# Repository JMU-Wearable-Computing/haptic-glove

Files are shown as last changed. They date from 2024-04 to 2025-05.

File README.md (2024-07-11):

# haptic-glove

## Haptic Effect Waveforms
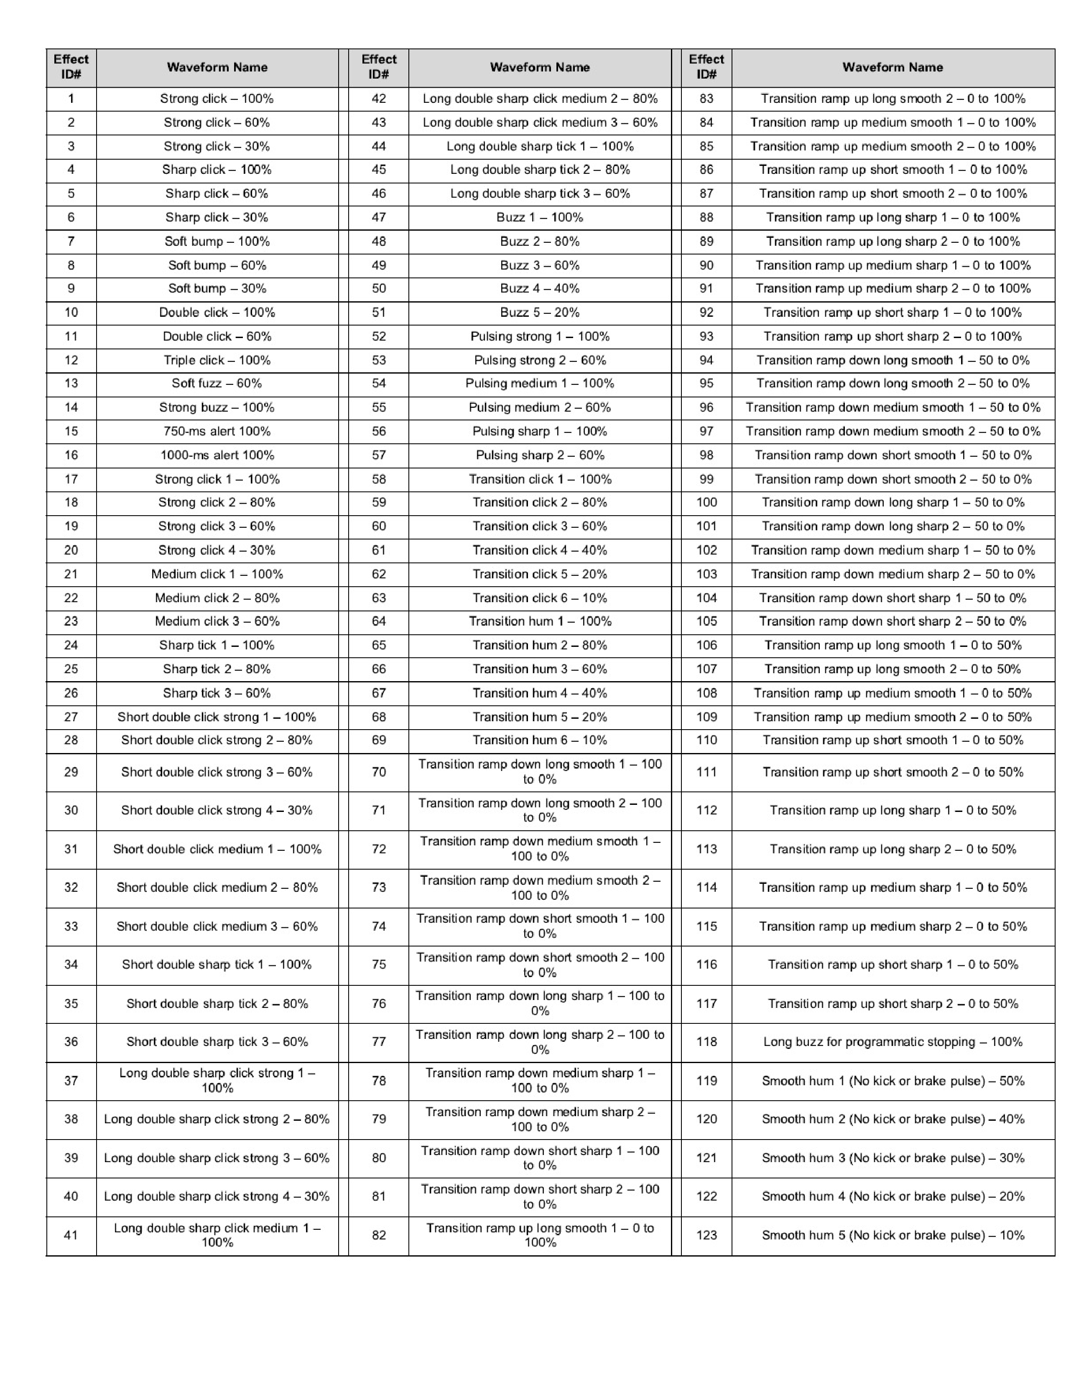
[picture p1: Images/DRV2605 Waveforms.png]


[Image source](https://learn.adafruit.com/assets/72593)

## PCB (Printed Circuit Board)

### Schematic V2.1
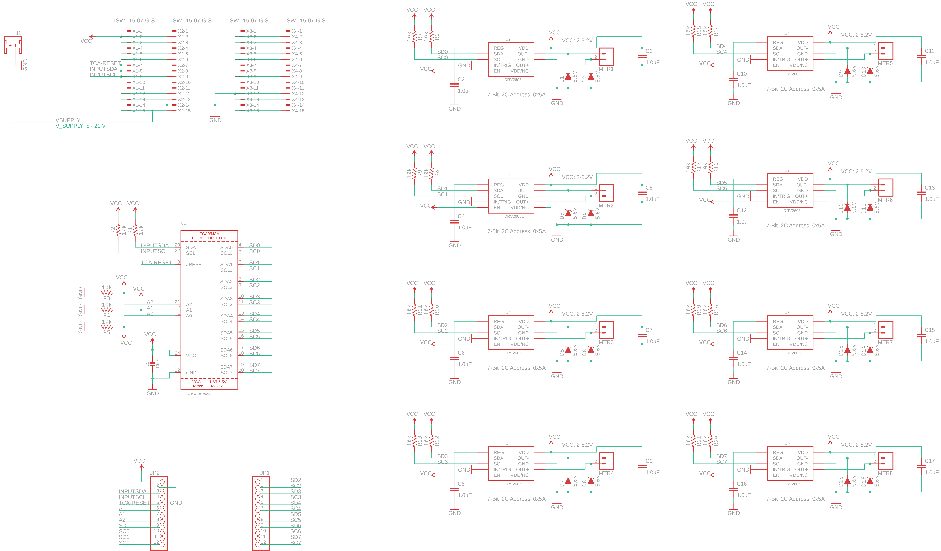
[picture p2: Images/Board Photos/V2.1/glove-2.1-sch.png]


### Layout V2.1
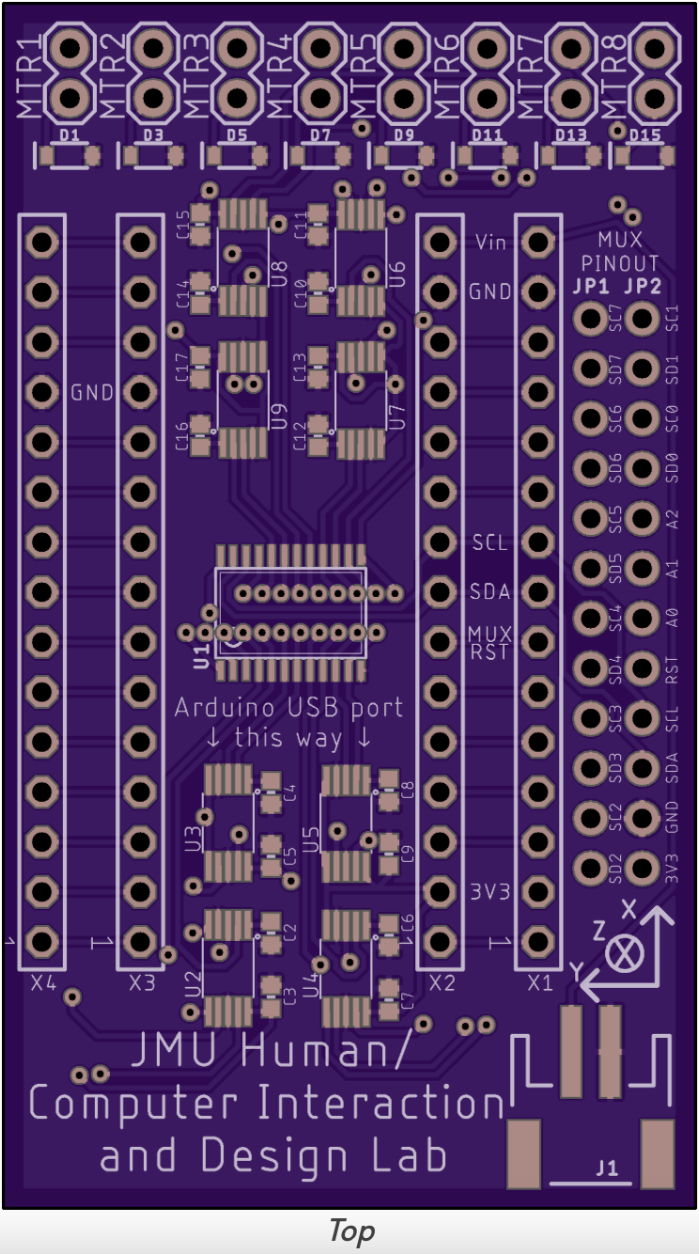
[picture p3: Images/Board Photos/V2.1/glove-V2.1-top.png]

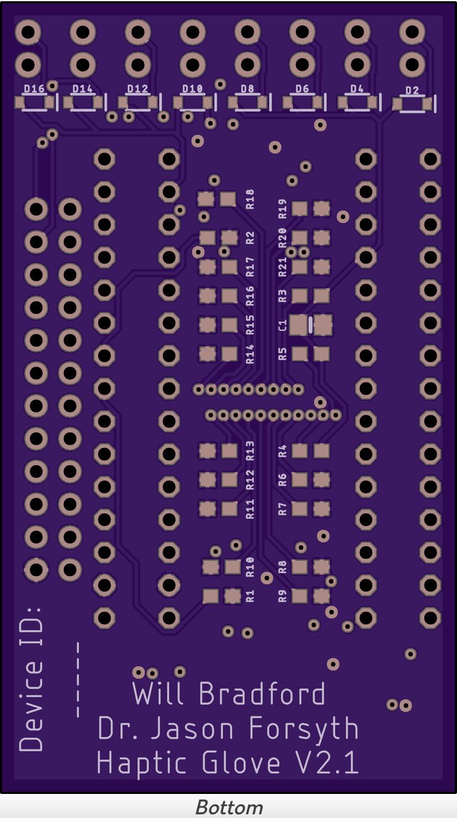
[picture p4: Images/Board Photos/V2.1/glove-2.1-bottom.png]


#### PCB Edit History
##### V2.0
- Initial board redesign
##### V2.1
- Shifted Arduino placement down 1 mm to allow for more clearance between the Arduino and the motor header pins
- Added graphic to denote onboard IMU directions
- Added a spot on the back of the board to write the board's device ID
- Shifted some silkscreen placements so that part names are not cut off by pads
- Added text to denote correct Arduino orientation
  
## Eagle PCB Set-Up

### OSHPark Plugin
The OSHPark Eagle plugin includes OSHPark design rules and allows the user to send the .brd file directly to an OSHPark cart. See the [OSHPark-Eagle-Tools GitHub](https://github.com/OSHPark/OSHPark-Eagle-Tools)

### Libraries
Included in the repository are:
1. TCA9548APWR.lbr (I2C multiplexer)
2. SparkFun-Eagle-Libraries-main.zip

## Arduino Nano Arduino IDE setup 

### Correct IDE version
Arduino IDE 2.X.X

### Correct board library and name:
#### Board Library
Arduino SAMD Boards (32-bits ARM Cortex-M0+)

#### Board Name
Arduino NANO 33 IoT

### Arduino Libraries
 
1. Adafruit_DRV2605.h
2. Arduino_LSM6DS3.h
3. WiFiNINA.h

### Troubleshooting
Sometimes, Arduino IDE fails to recognize that Nano 33 IoT is connected to a USB port. Should this happen, try the following fixes:
- Attempt to connect it to other USB ports on your machine
- If the above does not work, quickly double click the `RST` button on the Arduino while it is plugged into your machine. This will cause your Arduino's bootloader to run indefinitely. You will know that it has entered this state when you see the onboard LED slowly pulsing on and off. Arduino IDE should now recognize it and you should now be able to upload code.

If neither of these options work, then it is likely that either

(A). the bootloader on the Arduino is missing or corrupted, or  
(B). there is some hardware damage on the Arduino.

Sources: [Forum post 1](https://forum.arduino.cc/t/solved-arduino-nano-33-iot-not-recognized-by-windows-10/621376) & [Forum post 2](https://forum.arduino.cc/t/arduino-nano-33-iot-not-recognized-by-pc/1192703/4)

## Communicating with Nano 33 IoT

Nano 33 IoT can be communicated with via TCP socket connection.
Network credentials can be modified with the `ssid` and `password` variables within the Arduino code.
When booted, the Nano 33 IoT establishes a user definable static IP.

### Onboard LED state meanings
|State|Meaning|
--- | --- |
|OFF|Not connected to network|
|ON|Connected to user specified network|

### Message format
Messages follows the format: `X,n01,n02,n03,n04,n05,n06,n07,n08`

**NOTE FOR SERIAL COMMUNICATION ONLY:** Despite the known issue with [the dastardly eighth motor driver](#the-dastardly-eighth-motor-driver), the message format remains the same. Even if you are not using all eight drivers in your application with Serial communication, values for all eight drivers should be passed if you are sending an [effect message](#effect-messages) unless you are sending an [all stop message](#all-stop-message).

X is a char that signifies the message type. nXX is a number.
Negative numbers will be ignored and the playback of the current haptic effect will continue.
0 will stop the corresponding driver.
All decimals will be rounded DOWN.
Each segment of the message correspondes to the strength of a specific haptic driver, where n01 controls driver 1, n02 controls driver 2, and so on.

#### Effect Messages
For messages of type 'E', numbers [1, 123] will set the playback effect of the corresponding driver.
Numbers higher than 123 will set the playback effect to effect # 123.

##### All Stop Message
Should you want to halt the haptic playback of all drivers, simply passing `'E'` as the entire effect message will do this.

##### Example
The message `'E',100,43,55,1,123,34,99,2` will cause driver one to activate using haptic effect # 100, driver two to activate using haptic effect # 43, and so on. Passing the message `'E',0,-1,100.7,9999,0,0,0,0` afterwards will stop drivers 1, 5, 6, 7, and 8. Driver 2 will remain activated with the same haptic effect as before (# 43), driver 3 will activate using haptic effect # 100, and driver 4 will activate using haptic effect # 123.

#### Acceleration Messages
For messages of type 'A', numbers are used to toggle the continuous collection of acceleration data. Only one number should be passed. Passing the number zero will halt data collection, while any other number will resume data collection. For simplicity's sake, it is recommended to only use the number one to resume data collection. Once started, data will be continuously returned and sent to the client until another acceleration message is recieved that instructs the system to halt data collection.

##### Example
The message `'A',1` will begin continuous acceleration data collection and sending. The message `'A',0` will halt all acceleration data collection and sending.

## Tutorials
### Arduino IDE setup
This will teach you how to set up the Arduino IDE for use of the haptic glove. Prior to following this tutorial, you should already have the Arduino IDE downloaded.

1. Open `firmware-V2.ino`. `network_cred.h` should automatically open in a separate tab
2. Click the `network_cred.h` tab at the top and input your WiFi credentials. Press <kbd>Command</kbd> + <kbd>S</kbd> to save your edits on a Mac (<kbd>Control</kbd> + <kbd>S</kbd> on Windows).
3. Open the Boards Manager by clicking the correct icon on the left of the IDE. Search for `nano 33 iot`. The one board library that should be shown is `Arduino SAMD Boards (32-bits ARM Cortex-M0+)`. Install this library. Feel free to install a newer version than what is shown in the picture.

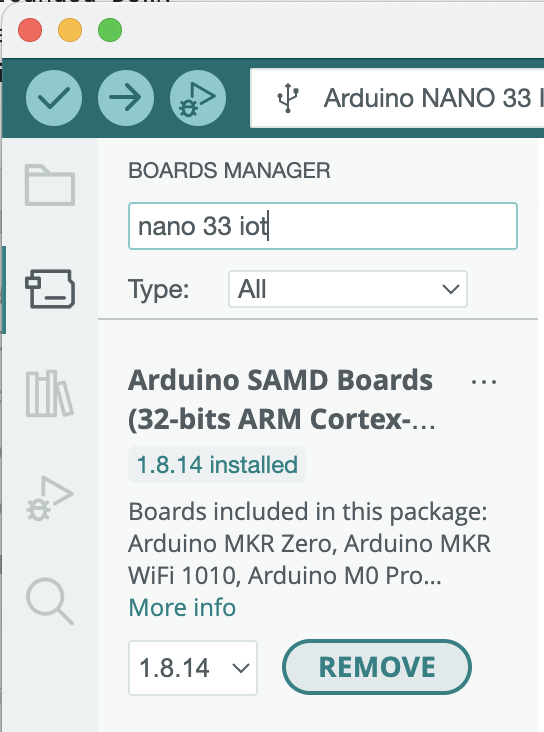
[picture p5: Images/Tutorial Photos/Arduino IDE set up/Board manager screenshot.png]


4. Open the Library manager by clicking the correct icon on the left of the IDE. Search for and install `Adafruit DRV2605 Library`, `Arduino_LSM6DS3` and `WiFiNINA`. Feel free to install newer versions than what are shown in the pictures.

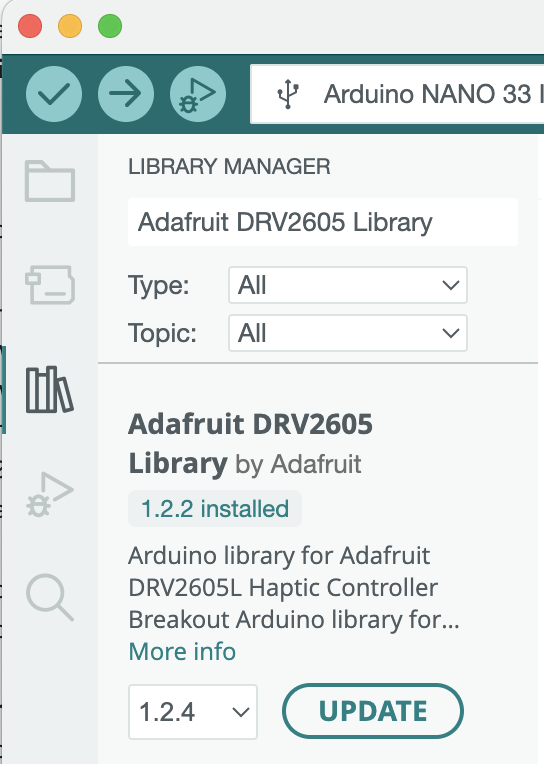
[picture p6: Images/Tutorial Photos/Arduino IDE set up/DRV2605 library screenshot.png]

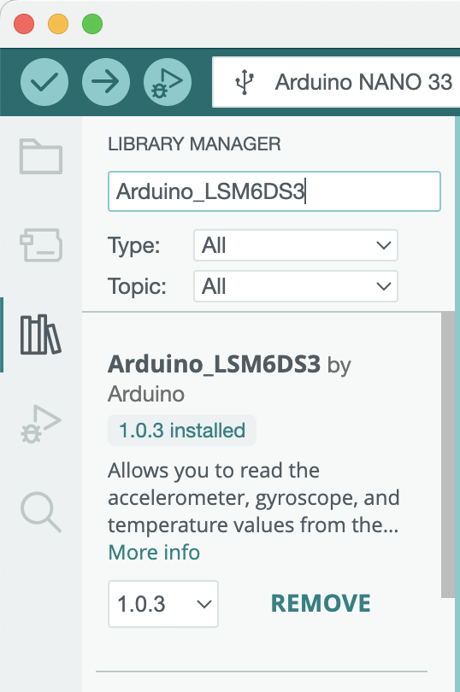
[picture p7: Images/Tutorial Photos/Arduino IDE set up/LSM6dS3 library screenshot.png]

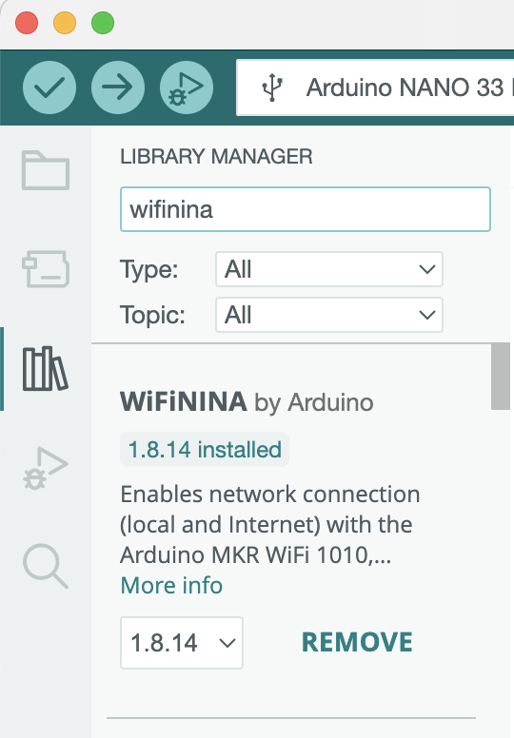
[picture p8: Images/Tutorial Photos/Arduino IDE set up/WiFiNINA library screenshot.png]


5. Navigate to `Tools`>`Board`>`Arduino`>`SAMD Boards (32-bits ARM Cortex-M0+)` and select `Arduino Nano 33 IoT` as the board.
6. Congratulations! Arduino IDE is now set up to be used with the haptic glove.

### Communicating with the Arduino via serial port
This will teach you how to send messages to the Arduino via the Serial port that will control the haptic motor drivers and the onboard IMU.

#### Initial Arduino set up
1. Complete the [Arduino IDE setup tutorial](#arduino-ide-setup).
2. Set the user-definable variables in the firmware. The value of the variable `DEVICE_ID` does not matter when using serial communication.



**NOTE:** See the [Known Issues section](#known-issues) for an explanation of `theDastardlyEighthDriver`

3. Ensure that the Serial Monitor baud rate is set to 9600



4. Connect the Arduino to your computer via USB, ensure the correct board and port are selected in the Arduino IDE, and upload the firmware by clicking the arrow button in the top left of the IDE.

#### Example Use
We will use an example message that was used in the [Message Format section](#message-format). Feel free to use other example messages from that section to familiarize yourself with the message structure. Or, be brave and create your own message (just be sure to follow the correct structure!)

##### Turning all drivers on with an effect message
1. In the serial monitor, type the following message and then press <kbd>Enter</kbd> (enter it EXACTLY as it appears here): `E,100,43,55,1,123,34,99,2`



2. If the variable `debug` is set to `true`, the following should be the last of what prints to the Serial Monitor:

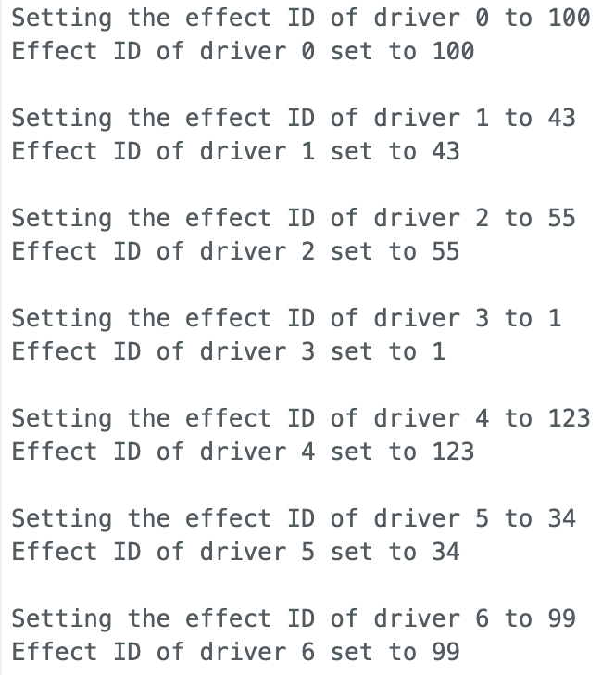
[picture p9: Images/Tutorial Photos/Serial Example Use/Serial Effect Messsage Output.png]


3. All drivers should now be activated. Driver number 1 should be set to haptic effect # 100, driver number 2 should be set to haptic effect # 43, and so on.

##### Accessing the accelerometer data using an acceleration message
1. In the serial monitor, type the following message and then press <kbd>Enter</kbd> (enter it EXACTLY as it appears here): `A,1`



2. As long as the variable `debug` is set to `true`, the following should print to the Serial Monitor. `outMsg` is the object that is sent to the TCP client. Acceleration data is now being continuously collected.

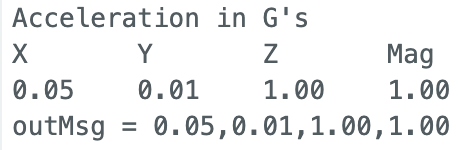
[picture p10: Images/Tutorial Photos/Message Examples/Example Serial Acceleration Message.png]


3. Now input the message `A,0` or just simply `A` into the Serial Monitor. Notice how the continuous collection of accelerometer data has stopped.

### Communicating with the Arduino via TCP socket connection
This will teach you how to send messages to the Arduino via a TCP socket to control the haptic motor drivers and the onboard IMU.

#### Initial Arduino set up
1. Complete the [Arduino IDE setup tutorial](#arduino-ide-setup).
2. Set the user-definable variables in the firmware. Be sure to set `DEVICE_ID` to a unique integer [10, 100].



3. Connect the Arduino to your computer via USB, ensure the correct board and port are selected in the Arduino IDE, and upload the firmware by clicking the arrow button in the top left of the IDE.
4. Once uploaded, you can safely unplug the Arduino from your computer. Congratulations! Your Arduino now has the necessary software and is ready for use with the haptic glove.

#### Setting up Python
This assumes that you already have Python installed and can successfully run a Python script.
1. Clone this repository (glove-V2) to your local computer
2. Open the repository in your preferred IDE (PyCharm is recommended)
3. Congrats! Python is now ready for use with the haptic glove.

#### Example Use
We will use `glove-demo-single.py` for this example. This is meant as a demonstration of the glove-V2 capabilities so that you can go on and create your own applications using the same methods.

1. After cloning this repository, open `glove-demo-single.py`
2. Ensure the correct parameters are set for the Glove object (`device_id`, `port`, `acceleration`, and `verbose`). Explanations for these parameters are in this Python file
3. The demo script is now ready for use. You can go ahead and run it, or customize the effect numbers that are sent to the glove.

**NOTE:** If you choose to activate the accelerometer on the Arduino (this is the default) then be sure that the `acceleration` property of the glove object is set to `True`. This will turn on continuous transmission of acceleration data until the Python script ends. Be sure that `glove.accel_loop` is set to `False` at the end of this example script. Otherwise, the program will be stuck in a loop and will continue to output acceleration data until the program is manually killed.

## Known Issues
### The Dastardly Eighth Motor Driver
#### Explanation and Recommendation
If you are attempting to control the motor drivers via TCP socket connection, attempting to activate the eighth driver (including if you tell it to halt effect playback by passing a zero in the correct place in an [effect message](#effect-messages) when it is already not activated) will cause the WiFi to disconnect. This will prevent reconnection until the onboard WiFi chip is fully turned off/on again by calling `WiFi.end()` and then the custom `WiFiConnect()` function that performs all of the initial WiFi connection procedures. Because of the nature of TCP socket connections, this requires the Arduino and desktop computer to restart their connection and create a new socket and client, at which point the problem will (99 times out of 100) happen again. To remedy this, the boolean variable `theDastardlyEighthDriver` has been added to the firmware that controls the use of the eighth driver. If you are at all using TCP socket connections with the haptic glove, be sure to keep this variable set to `false` so that the WiFi disconnect problem does not occur. You will only be able to use seven of the eight drivers, but the WiFi connection will be reliable and shouldn't drop. If you are strictly using Serial communication to control the motor drivers, then feel free to set `theDastardlyEighthDriver` to `true`. This will allow you to use all eight drivers for your application.
#### Potential Cause
The current theory for why this issue is happening is that the moment the I2C multiplexer begins to communicate with this eighth driver, since the driver's I2C lines are tied high and the mux pulls them low to communicate, power and ground are very briefly shorted. It is believed that this short then messes with the WiFi chip's power supply, causing WiFi to drop and requiring the WiFi chip to be reset.

This issue is present on all of the existing haptic glove V2.0 boards, so it is not believed that it is simply an issue with the soldering of the components, however this is still a possibility. However, it may be a tolerance issue with the traces on the PCB itself. As of now (May 2024), no V2.1 boards have been fabricated so it is unknown if this issue is present on those (although it is likely that it is). Also, it is worth noting that during fabrication of the PCBs there was a power-ground short somewhere that disappeared before we could track down the cause. It disappeared once all components were soldered onto the PCB. This may be related to the problem explained above, although there is no corroborating evidence to prove that this is the case.

The true cause of this issue is unknown, so it is best to utilize the `theDastardlyEighthDriver` variable to only use seven drivers if your application uses TCP sockets.

# Recommendations for Future Work
## Software Development
### General
Explore both `firmware-V2` and the Python scripts to both:
- Familiarize yourself with the workings of each, and
- Look at and address the various "TODO:" comments that are shrewn throughout.
### VS Code
Install [PlatformIO](https://docs.platformio.org/en/latest/integration/ide/vscode.html#ide-vscode) for VS Code to develop Arduino code. Also look at [this link](https://docs.platformio.org/en/latest/boards/atmelsam/nano_33_iot.html#board-atmelsam-nano-33-iot) to learn how to set up VS Code to use the Nano 33 IoT within PlatformIO.
### Checksum/Parity Check
Implement a checksum to verify the authenticity of each message recieved over TCP Socket
- We ran into some trouble implementing this, so we abandoned our efforts since this is a secondary feature that is not necesary for the design. There is already some rudimentary draft code in `firmware-V2` and `glove.py`
### Implementing Threads
Update `firmware-V2` to utilize threads for each main process (managing WiFi & onboard LED, controlling the haptic motor drivers, and receiving/parsing messages from both Serial and TCP Socket). We have been looking at and prototyping with [Arduino Free RTOS SAMD21](https://github.com/BriscoeTech/Arduino-FreeRTOS-SAMD21/tree/master) for this.
#### Onboard LED state meanings
Make it to where the below table is what happens
|State|Meaning|
--- | --- |
|OFF|Not connected to network|
|BLINKING|Connected to user specified network|
|SOLID|TCP client connected and ready for messages|

### Message Parser
#### Implement custom parser rather than strtok()
Currently, `firmware-V2` uses the built in function `strtok()` to parse received messages. This function has state and remembers the delimeter. Change the parsing process to use a custom parser so that this pipeline is more reliable and does not have state.
#### Make message system more robust
- Sometimes the software freezes if message does not contain instructions for all 8 motors

## Debugging the Arduino using an Atmel-ICE
Look into some surface mounted pins or magnetic pins to access the Arduino's debug pins on the underside of the Arduino. Learn how to use the Atmel-ICE to interface with these pins to debug the Arduino. Refer to [this PlatformIO link](https://docs.platformio.org/en/latest/boards/atmelsam/nano_33_iot.html#board-atmelsam-nano-33-iot) and [this SAM-based Arduino debugging tutorial](https://docs.arduino.cc/tutorials/mkr-wifi-1010/atmel-ice/) for reference for the beginning of your search of how to debug the Nano 33 IoT with the Atmel-ICE.

## Reworking Python Haptic Glove Game & Demo to Work with Glove V2
The lab's glove demos currently only work with V1 of both the glove and Python code. Update these demos to work with the V2 glove and Python code. This will likely require some internal restructuring of the demos themselves.

## PCB Revision
### 5V Step Up Converter
When using battery power for glove V2, a 5V boost/step up converter must be used to provide the Arduino with enough voltage. as of Spring 2024, we are using a [PowerBoost 1000 Basic](https://www.adafruit.com/product/2030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) breakout board from Arduino for this. Make a new PCB revision that includes this boost converter and all required circuitry onto the PCB itself.

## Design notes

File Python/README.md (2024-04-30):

glove.py = Base class for haptic glove object

glove-demo-single.py = Example to test haptic motor functionality of one glove

glove-demo-multiple.py = Example to test haptic motor functionality of two or more gloves

echo.py = Echo script to test TCP socket communication

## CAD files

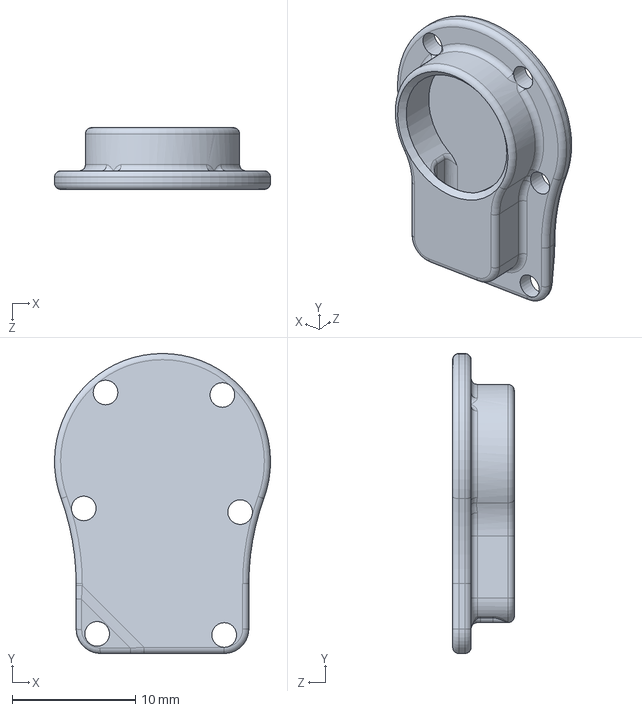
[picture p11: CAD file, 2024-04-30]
Solidworks/Haptic motor housing.SLDPRT
17.5 x 24.3 x 5.00 mm

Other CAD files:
Solidworks/Haptic motor housing.STL

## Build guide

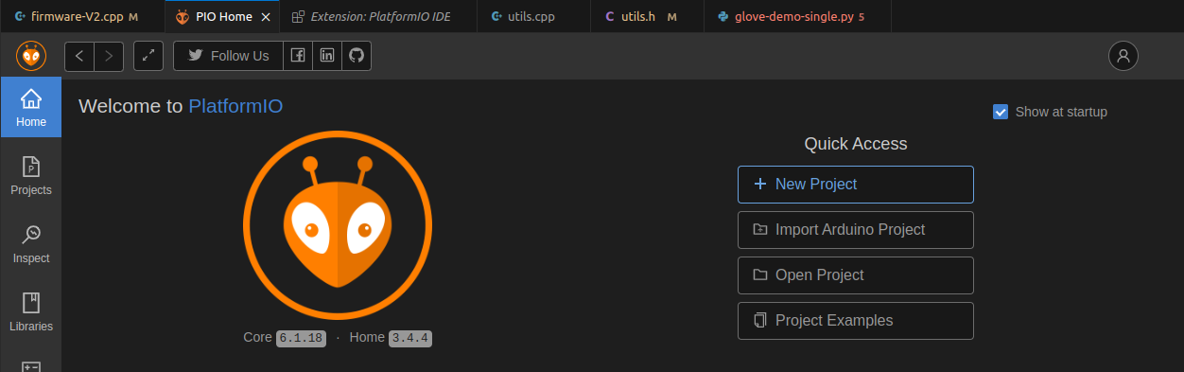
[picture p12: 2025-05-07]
Images/Tutorial Photos/PlatformIO Setup/add_new_project.png

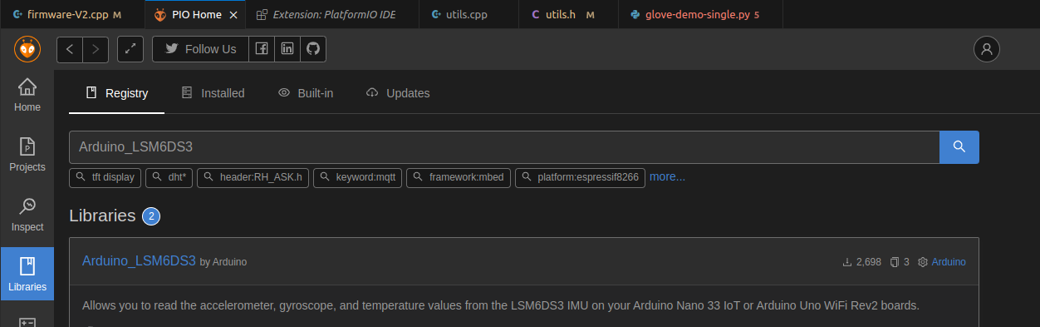
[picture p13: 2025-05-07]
Images/Tutorial Photos/PlatformIO Setup/lsm_library.png

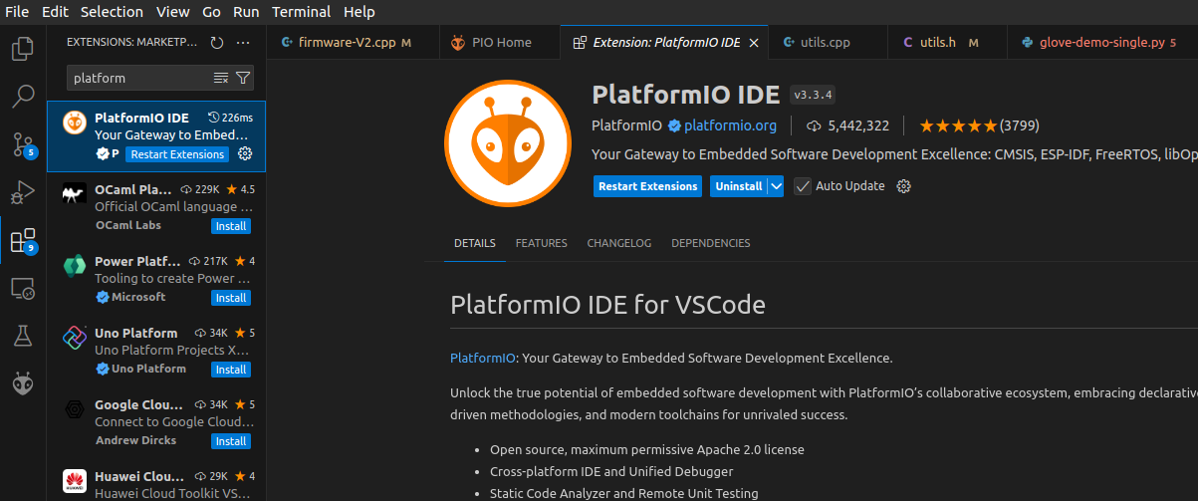
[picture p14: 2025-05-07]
Images/Tutorial Photos/PlatformIO Setup/install_extension.png

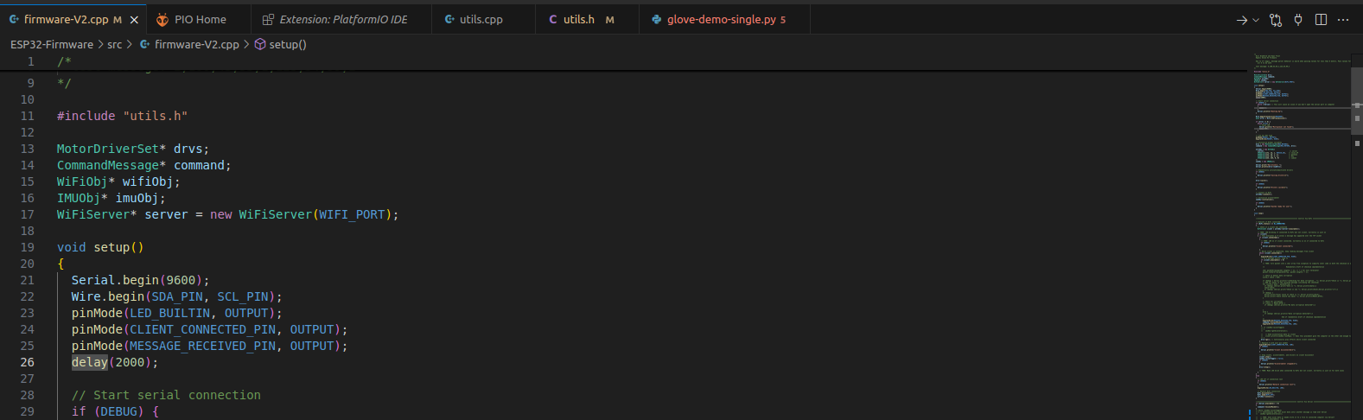
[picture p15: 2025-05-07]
Images/Tutorial Photos/PlatformIO Setup/upload_button.png

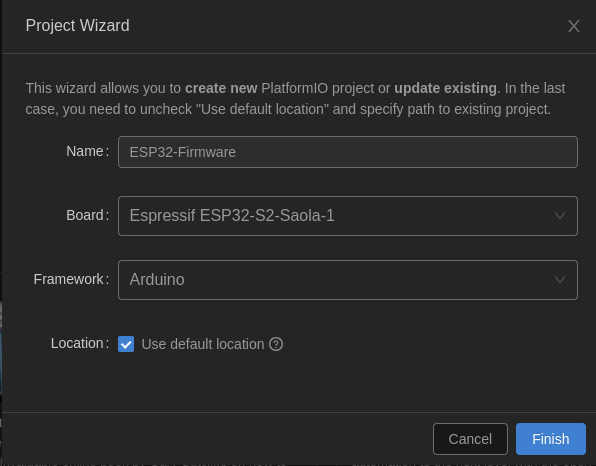
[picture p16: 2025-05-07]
Images/Tutorial Photos/PlatformIO Setup/new_project_board_selection.png

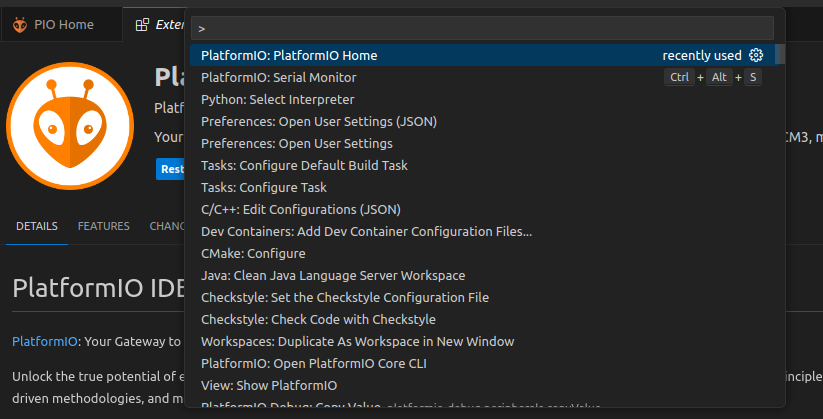
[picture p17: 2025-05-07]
Images/Tutorial Photos/PlatformIO Setup/navigate_to_home.png

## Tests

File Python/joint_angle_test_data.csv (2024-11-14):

1.23 | Capture Frame Rate | 120 | Export Frame Rate
Type | Rigid Body | Rigid Body | Rigid Body | Rigid Body | Rigid Body | Rigid Body | Rigid Body | Rigid Body | Rigid Body
Name | Shoulder_Suit | Shoulder_Suit | Shoulder_Suit | Elbow_Suit | Elbow_Suit | Elbow_Suit | Hand_Suit | Hand_Suit | Hand_Suit
ID | 5F10C191754A11EF7E5C15E596CCCB90 | 5F10C191754A11EF7E5C15E596CCCB90 | 5F10C191754A11EF7E5C15E596CCCB90 | 66B905C7754A11EF7E5C15E596CCCB90 | 66B905C7754A11EF7E5C15E596CCCB90 | 66B905C7754A11EF7E5C15E596CCCB90 | 70C6742A754A11EF7E5C15E596CCCB90 | 70C6742A754A11EF7E5C15E596CCCB90 | 70C6742A754A11EF7E5C15E596CCCB90
 | Position | Position | Position | Position | Position | Position | Position | Position | Position
Time (Seconds) | X | Y | Z | X | Y | Z | X | Y | Z
2.067 | 245.039825 | 1333.517578 | 2644.715332 | 123.601738 | 1044.49707 | 2604.020264 | -15.629079 | 888.19751 | 2742.276123
2.075 | 243.548187 | 1334.413574 | 2638.129639 | 123.601738 | 1044.49707 | 2604.020264 | -17.779198 | 889.066284 | 2737.969238
2.083 | 240.272583 | 1333.587402 | 2630.972168 | 123.601738 | 1044.49707 | 2604.020264 | -19.277227 | 889.89563 | 2733.742676
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

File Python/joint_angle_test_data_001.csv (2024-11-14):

Format Version | 1.23 | Capture Frame Rate | 120 | Export Frame Rate | Coordinate Space | Local
 | Type | Rigid Body | Rigid Body | Rigid Body | Rigid Body | Rigid Body | Rigid Body | Rigid Body | Rigid Body | Rigid Body
 | Name | Shoulder | Shoulder | Shoulder | Elbow | Elbow | Elbow | Hand | Hand | Hand
 | ID | 5DFF20EB776D11EF7E5C15E596CCCB90 | 5DFF20EB776D11EF7E5C15E596CCCB90 | 5DFF20EB776D11EF7E5C15E596CCCB90 | 87D58C47776E11EF7E5C15E596CCCB90 | 87D58C47776E11EF7E5C15E596CCCB90 | 87D58C47776E11EF7E5C15E596CCCB90 | 93EE6B15776E11EF7E5C15E596CCCB90 | 93EE6B15776E11EF7E5C15E596CCCB90 | 93EE6B15776E11EF7E5C15E596CCCB90
 |  | Position | Position | Position | Position | Position | Position | Position | Position | Position
Frame | Time (Seconds) | X | Y | Z | X | Y | Z | X | Y | Z
0 | 0 | -319.861908 | 15.166142 | 804.370361 | 201.799713 | 14.984299 | 711.681763 | 310.022858 | 7.533872 | 1226.356323
1 | 0.008 | -319.859406 | 15.161272 | 804.372986 | 201.769928 | 14.976796 | 711.660156 | 310.013153 | 7.54616 | 1226.359009
2 | 0.017 | -319.865326 | 15.167896 | 804.364258 | 201.772186 | 14.975074 | 711.663391 | 309.988922 | 7.571316 | 1226.358765
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

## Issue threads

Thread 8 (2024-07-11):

Remove DEVICE_ID and replace with DEVICE_IP

jforsyth, 2024-07-11:
Remove the notion of DEVICE_ID as it hard codes the private network information. Simply assume each object has its own IP address. Connect and refer to it in this manner.

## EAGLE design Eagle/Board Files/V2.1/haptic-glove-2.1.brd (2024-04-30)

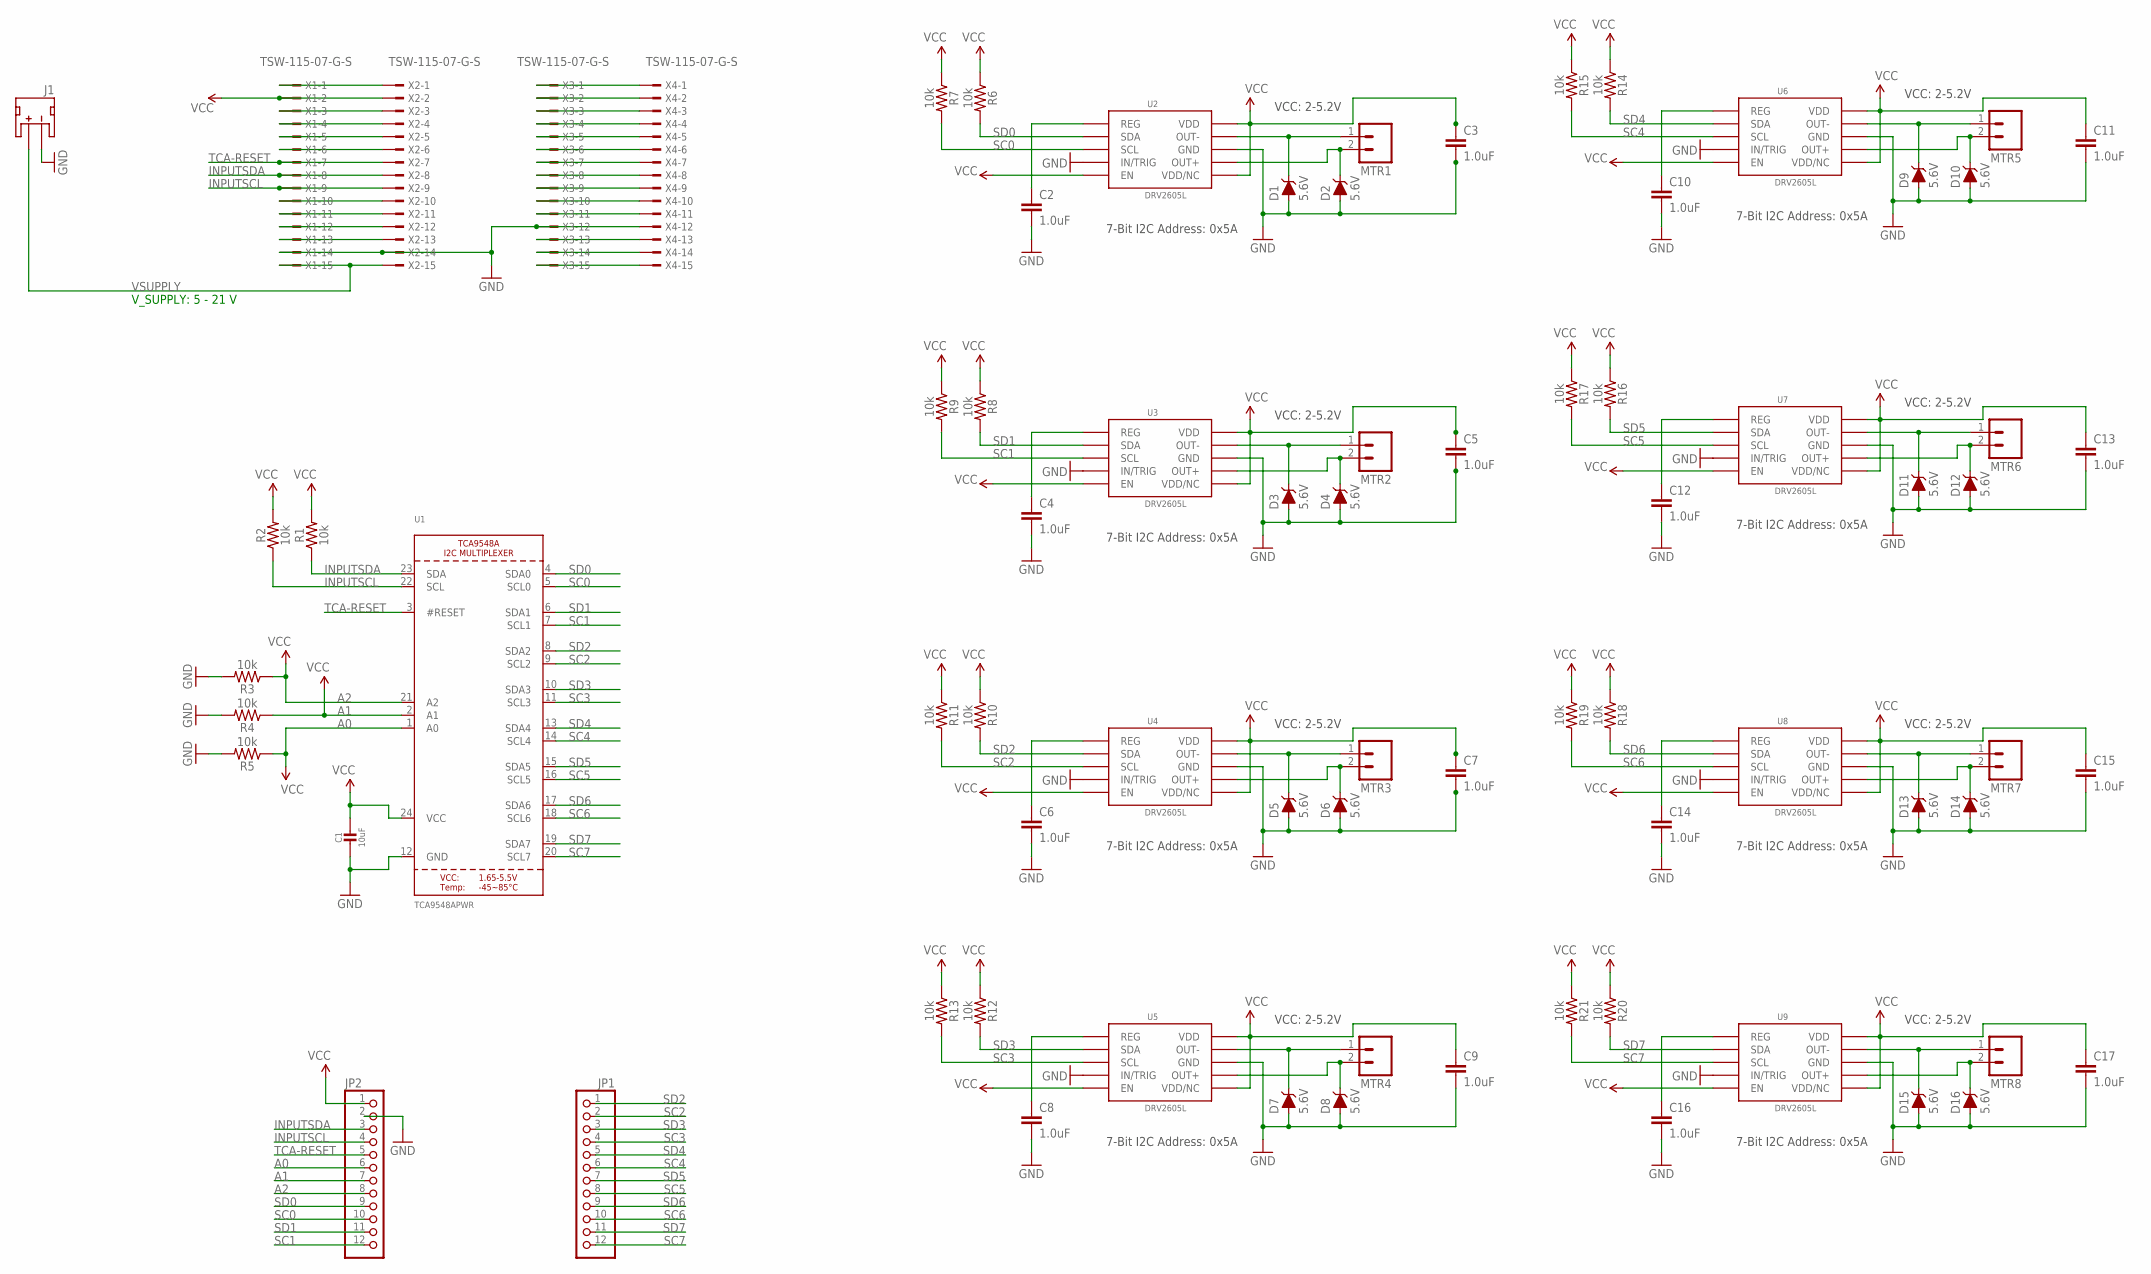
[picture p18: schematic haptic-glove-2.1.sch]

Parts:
C1: 10uF; 0805-NO
C2, C3, C4, C5, C6, C7, C8, C9, C10, C11, C12, C13, C14, C15, C16, C17: 1.0uF; 0402-CAP; MPN GRM155R61E105KA12D
D1, D2, D3, D4, D5, D6, D7, D8, D9, D10, D11, D12, D13, D14, D15, D16: 5.6V; SOD-323
J1: JST_2MM_MALE; JST-2-SMD
JP1, JP2: HEADER-1X12; 1X12_ROUND
MTR1, MTR2, MTR3, MTR4, MTR5, MTR6, MTR7, MTR8: M02PTH; 1X02@1
R1, R2, R3, R4, R5, R6, R7, R8, R9, R10, R11, R12, R13, R14, R15, R16, R17, R18, R19, R20, R21: 10k; 0603
U1: TCA9548APWR; TSSOP24
U2, U3, U4, U5, U6, U7, U8, U9: DRV2605L; VSSOP-10
X1, X2, X3, X4: TSW-115-07-G-S; TSW-115-XX-G-S

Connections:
A0: JP2.6, R5.1, U1.1 (A0)
A1: JP2.7, R4.1, U1.2 (A1)
A2: JP2.8, R3.1, U1.21 (A2)
EN1: X3.2, X4.2
EN2: X3.4, X4.4
EN3: X3.8, X4.8
EN4: X3.11, X4.11
GND: C1.2, C2.2, C3.2, C4.2, C5.2, C6.2, C7.2, C8.2, C9.2, C10.2, C11.2, C12.2, C13.2, C14.2, C15.2, C16.2, C17.2, D1.A, D2.A, D3.A, D4.A, D5.A, D6.A, D7.A, D8.A, D9.A, D10.A, D11.A, D12.A, D13.A, D14.A, D15.A, D16.A, J1.1 (-), JP2.2, R3.2, R4.2, R5.2, U1.12 (GND), U2.P$4 (IN/TRIG), U2.P$8 (GND), U3.P$4 (IN/TRIG), U3.P$8 (GND), U4.P$4 (IN/TRIG), U4.P$8 (GND), U5.P$4 (IN/TRIG), U5.P$8 (GND), U6.P$4 (IN/TRIG), U6.P$8 (GND), U7.P$4 (IN/TRIG), U7.P$8 (GND), U8.P$4 (IN/TRIG), U8.P$8 (GND), U9.P$4 (IN/TRIG), U9.P$8 (GND), X1.14, X2.14, X3.12, X4.12
IN/TRIG1: X3.1, X4.1
IN/TRIG2: X3.3, X4.3
IN/TRIG3: X3.7, X4.7
IN/TRIG4: X3.10, X4.10
IN/TRIG5: X1.6, X2.6
INPUTSCL: JP2.4, R2.1, U1.22 (SCL), X1.9, X2.9
INPUTSDA: JP2.3, R1.1, U1.23 (SDA), X1.8, X2.8
unnamed: C4.1, U3.P$1 (REG)
unnamed: C10.1, U6.P$1 (REG)
unnamed: D9.C, MTR5.1, U6.P$9 (OUT-)
unnamed: D3.C, MTR2.1, U3.P$9 (OUT-)
unnamed: D4.C, MTR2.2, U3.P$7 (OUT+)
unnamed: C8.1, U5.P$1 (REG)
unnamed: D10.C, MTR5.2, U6.P$7 (OUT+)
unnamed: X1.1, X2.1
unnamed: D7.C, MTR4.1, U5.P$9 (OUT-)
unnamed: D8.C, MTR4.2, U5.P$7 (OUT+)
unnamed: C6.1, U4.P$1 (REG)
unnamed: X1.3, X2.3
unnamed: D5.C, MTR3.1, U4.P$9 (OUT-)
unnamed: D6.C, MTR3.2, U4.P$7 (OUT+)
unnamed: C12.1, U7.P$1 (REG)
unnamed: X1.4, X2.4
unnamed: D11.C, MTR6.1, U7.P$9 (OUT-)
unnamed: D12.C, MTR6.2, U7.P$7 (OUT+)
unnamed: C14.1, U8.P$1 (REG)
unnamed: X1.5, X2.5
unnamed: D13.C, MTR7.1, U8.P$9 (OUT-)
unnamed: D14.C, MTR7.2, U8.P$7 (OUT+)
unnamed: C16.1, U9.P$1 (REG)
unnamed: D15.C, MTR8.1, U9.P$9 (OUT-)
unnamed: D16.C, MTR8.2, U9.P$7 (OUT+)
unnamed: C2.1, U2.P$1 (REG)
unnamed: X1.10, X2.10
unnamed: X1.11, X2.11
unnamed: D1.C, MTR1.1, U2.P$9 (OUT-)
unnamed: D2.C, MTR1.2, U2.P$7 (OUT+)
unnamed: X1.12, X2.12
unnamed: X1.13, X2.13
unnamed: X3.5, X4.5
unnamed: X3.6, X4.6
unnamed: X3.9, X4.9
unnamed: X3.13, X4.13
unnamed: X3.14, X4.14
unnamed: X3.15, X4.15
SC0: JP2.10, R7.2, U1.5 (SCL0), U2.P$2 (SCL)
SC1: JP2.12, R9.2, U1.7 (SCL1), U3.P$2 (SCL)
SC2: JP1.2, R11.2, U1.9 (SCL2), U4.P$2 (SCL)
SC3: JP1.4, R13.2, U1.11 (SCL3), U5.P$2 (SCL)
SC4: JP1.6, R15.2, U1.14 (SCL4), U6.P$2 (SCL)
SC5: JP1.8, R17.2, U1.16 (SCL5), U7.P$2 (SCL)
SC6: JP1.10, R19.2, U1.18 (SCL6), U8.P$2 (SCL)
SC7: JP1.12, R21.2, U1.20 (SCL7), U9.P$2 (SCL)
SD0: JP2.9, R6.2, U1.4 (SDA0), U2.P$3 (SDA)
SD1: JP2.11, R8.2, U1.6 (SDA1), U3.P$3 (SDA)
SD2: JP1.1, R10.2, U1.8 (SDA2), U4.P$3 (SDA)
SD3: JP1.3, R12.2, U1.10 (SDA3), U5.P$3 (SDA)
SD4: JP1.5, R14.2, U1.13 (SDA4), U6.P$3 (SDA)
SD5: JP1.7, R16.2, U1.15 (SDA5), U7.P$3 (SDA)
SD6: JP1.9, R18.2, U1.17 (SDA6), U8.P$3 (SDA)
SD7: JP1.11, R20.2, U1.19 (SDA7), U9.P$3 (SDA)
TCA-RESET: JP2.5, U1.3 (#RESET), X1.7, X2.7
VCC: C1.1, C3.1, C5.1, C7.1, C9.1, C11.1, C13.1, C15.1, C17.1, JP2.1, R1.2, R2.2, R6.1, R7.1, R8.1, R9.1, R10.1, R11.1, R12.1, R13.1, R14.1, R15.1, R16.1, R17.1, R18.1, R19.1, R20.1, R21.1, U1.24 (VCC), U2.P$5 (EN), U2.P$6 (VDD/NC), U2.P$10 (VDD), U3.P$5 (EN), U3.P$6 (VDD/NC), U3.P$10 (VDD), U4.P$5 (EN), U4.P$6 (VDD/NC), U4.P$10 (VDD), U5.P$5 (EN), U5.P$6 (VDD/NC), U5.P$10 (VDD), U6.P$5 (EN), U6.P$6 (VDD/NC), U6.P$10 (VDD), U7.P$5 (EN), U7.P$6 (VDD/NC), U7.P$10 (VDD), U8.P$5 (EN), U8.P$6 (VDD/NC), U8.P$10 (VDD), U9.P$5 (EN), U9.P$6 (VDD/NC), U9.P$10 (VDD), X1.2, X2.2
VSUPPLY: J1.2 (+), X1.15, X2.15

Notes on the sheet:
7-Bit I2C Address: 0x5A
VCC: 2-5.2V
V_SUPPLY: 5 - 21 V

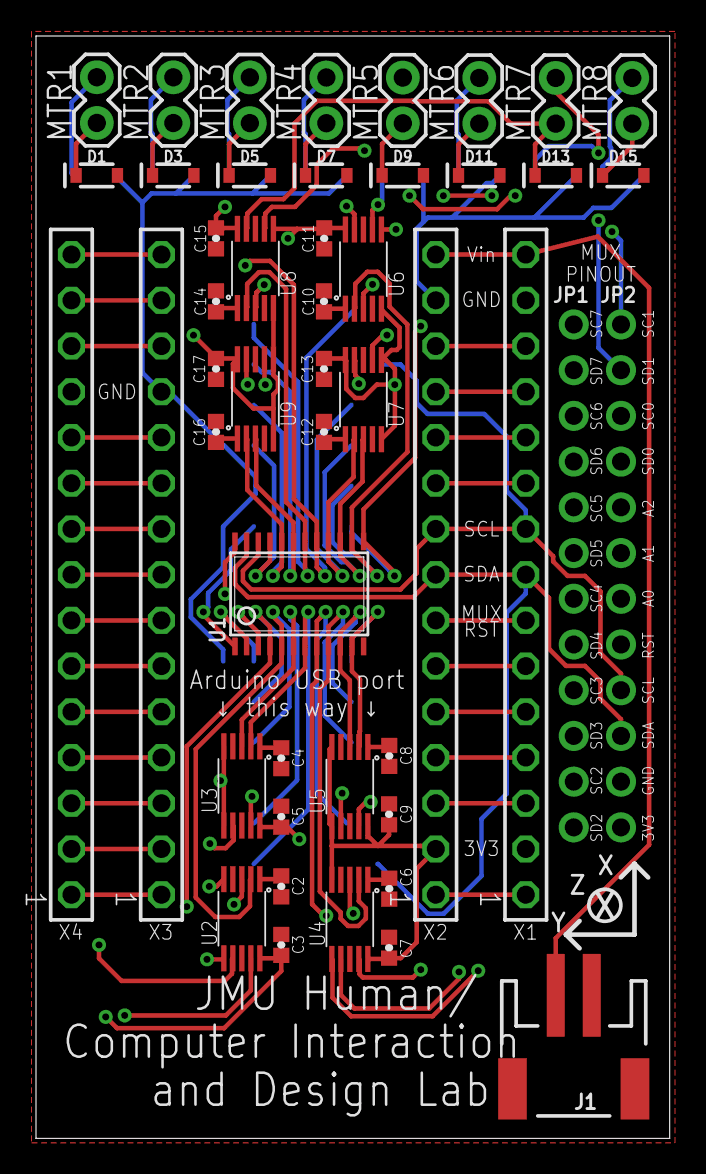
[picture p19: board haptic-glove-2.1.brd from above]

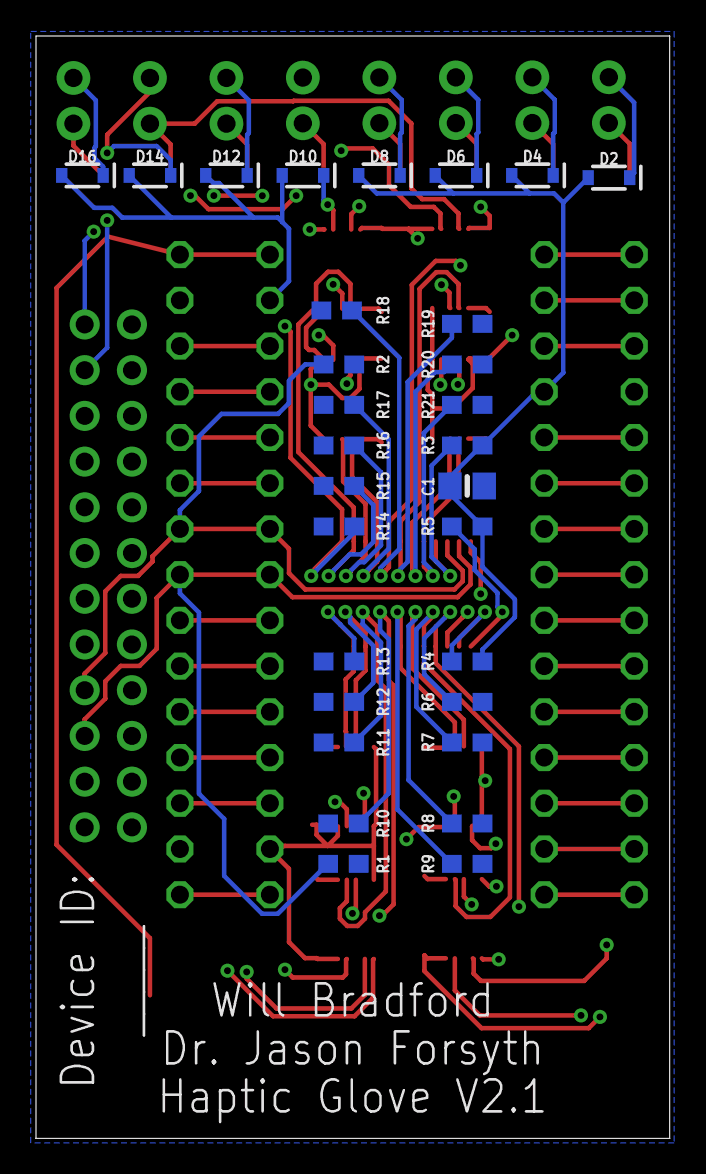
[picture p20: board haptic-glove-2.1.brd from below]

Board: 4 copper layers, 35.2 x 61.2 mm, 78 parts (30 on the bottom side), 72 nets.

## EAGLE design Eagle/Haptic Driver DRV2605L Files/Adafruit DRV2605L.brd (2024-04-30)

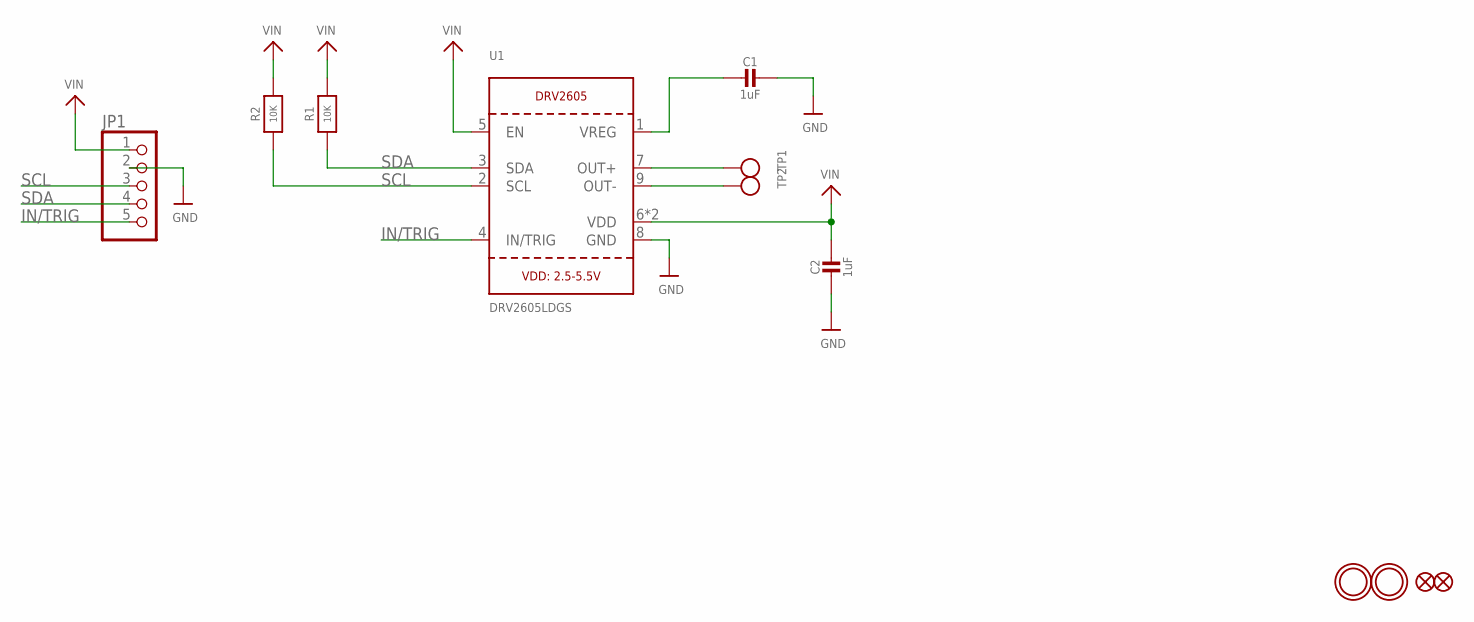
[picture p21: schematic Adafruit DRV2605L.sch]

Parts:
C1, C2: 1uF; 0805-NO
FID1, FID2: FIDUCIAL""; FIDUCIAL_1MM
JP1: HEADER-1X576MIL_FULL; 1X05_ROUND_FULL_76
R1, R2: 10K; 0805-NO
TP1, TP2: TESTPOINTPAD2MM; TESTPOINT_PAD_2MM
U1: DRV2605LDGS; PSOP10
U$2, U$3: MOUNTINGHOLE2.5; MOUNTINGHOLE_2.5_PLATED

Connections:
GND: C1.1, C2.2, JP1.2, U1.8 (GND)
IN/TRIG: JP1.5, U1.4 (IN/TRIG)
unnamed: C1.2, U1.1 (VREG)
OUT+: TP1.P$1, U1.7 (OUT+)
OUT-: TP2.P$1, U1.9 (OUT-)
SCL: JP1.3, R2.1, U1.2 (SCL)
SDA: JP1.4, R1.1, U1.3 (SDA)
VIN: C2.1, JP1.1, R1.2, R2.2, U1.5 (EN), U1.6 (VDD), U1.10 (VDD)

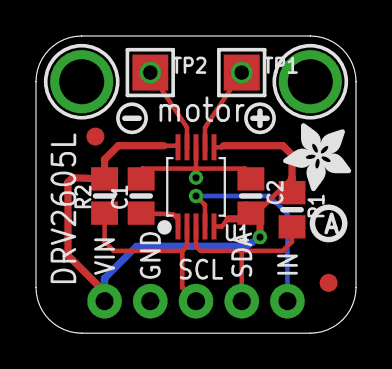
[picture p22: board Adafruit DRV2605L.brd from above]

Board: 2 copper layers, 17.8 x 16.5 mm, 16 parts (0 on the bottom side), 8 nets.

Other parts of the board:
U$4: SYMBOL_PLUS
U$5: SYMBOL_MINUS
U$15: PCBFEAT-REV-040
U$18: ADAFRUIT_3.5MM

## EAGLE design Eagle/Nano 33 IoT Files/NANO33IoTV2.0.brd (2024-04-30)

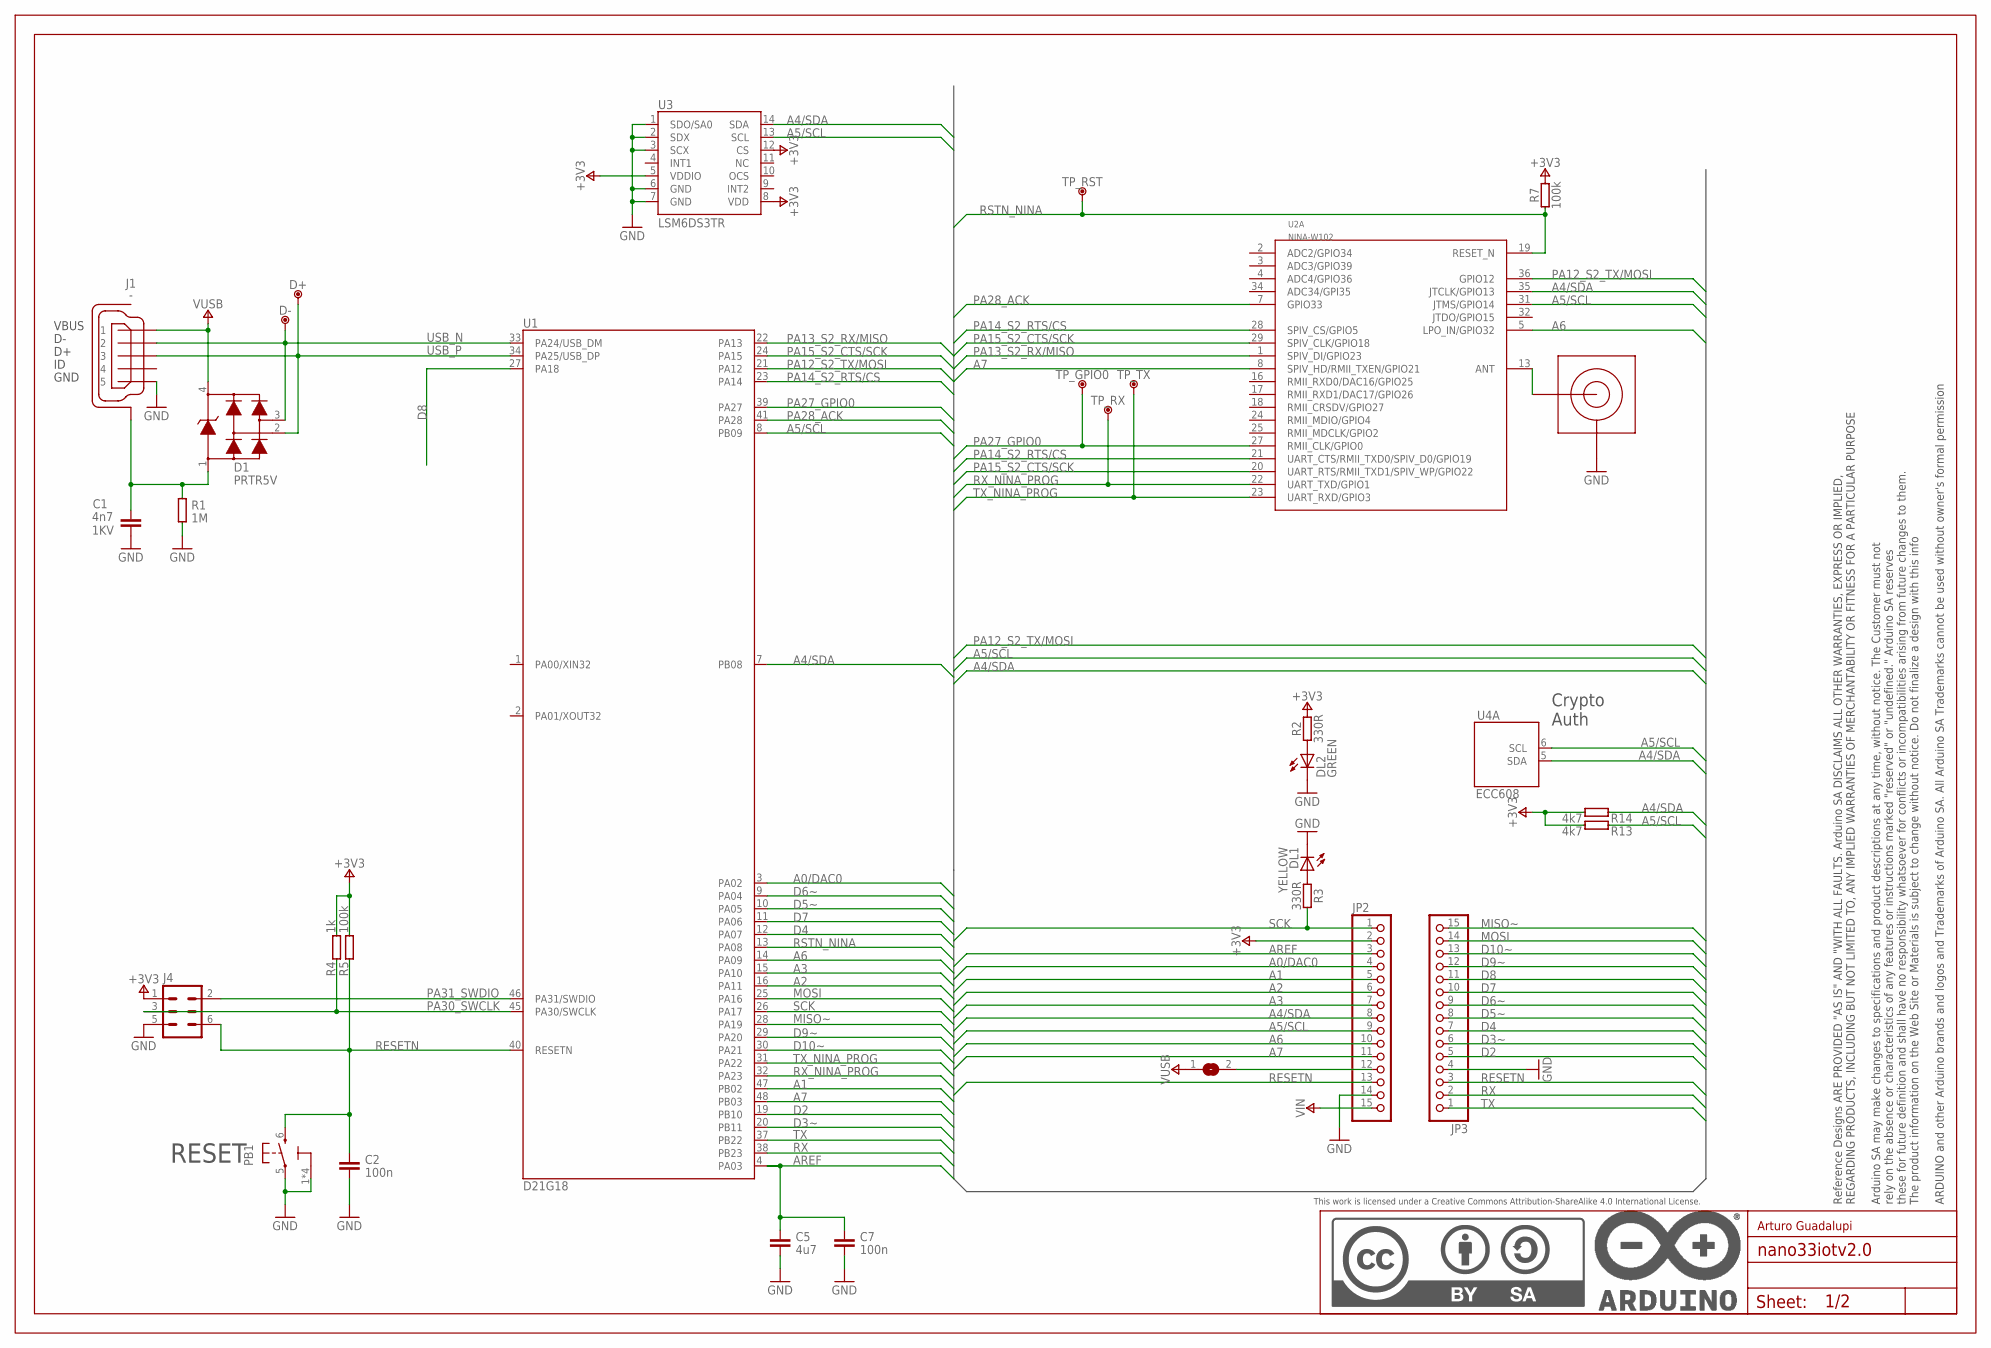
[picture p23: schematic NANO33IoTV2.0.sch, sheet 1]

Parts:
C1: 4n7; 0805-R2013X50N; VOLTAGE 1KV
C2, C7: 100n; 0402-1005X55N
C5: 4u7; 0402-1005X55N
D1: PRTR5V; SOT190P230X110-4N
D+: DNP; TP-1.00MM
D-: DNP; TP-1.00MM
DL1: YELLOW; LEDC1608X80N-AK
DL2: GREEN; LEDC1608X80N-AK
FRAME1: DNP; FRAME
J1: -; ZX62-AB-5PA
J3: DNP; U.FL-R-SMT-1(60)/NO_CREAM
J4: DNP; 2X03-TP1
JP2, JP3: PINHD-1X15-CASTELLATED; 1X15-CASTELL
PB1: PTS820; C&K_PTS820_NO_HOLES
R1: 1M; 0402-1005X55N
R2, R3: 330R; 0402-1005X55N
R4: 1k; 0402-1005X55N
R5, R7: 100k; 0402-1005X55N
R13, R14: 4k7; 0402-1005X55N
SJ1: DNP; SJ
TP_GPIO0: DNP; TP-0.8MM
TP_RST: DNP; TP-0.8MM
TP_RX: DNP; TP-0.8MM
TP_TX: DNP; TP-0.8MM
U1: D21G18; QFN50P700X700X90-49XN-EPSQ515
U2: NINA-W102; NINA-W1X
U3: LSM6DS3TR; LGA14L
U4: ECC608; SON50P300X200X60-9N-EP160X140

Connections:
+3V3: J4.1, JP2.2, R2.2, R4.2, R5.2, R7.2, R13.2, R14.2, U3.5 (VDDIO), U3.8 (VDD), U3.12 (CS); also elsewhere on the board
A0/DAC0: JP2.4, U1.3 (PA02)
A1: JP2.5, U1.47 (PB02)
A2: JP2.6, U1.16 (PA11)
A3: JP2.7, U1.15 (PA10)
A4/SDA: JP2.8, R14.1, U1.7 (PB08), U2.35 (JTCLK/GPIO13), U3.14 (SDA), U4.5 (SDA)
A5/SCL: JP2.9, R13.1, U1.8 (PB09), U2.31 (JTMS/GPIO14), U3.13 (SCL), U4.6 (SCL)
A6: JP2.10, U1.14 (PA09), U2.5 (LPO_IN/GPIO32)
A7: JP2.11, U1.48 (PB03), U2.8 (SPIV_HD/RMII_TXEN/GPIO21)
AREF: C5.1, C7.1, JP2.3, U1.4 (PA03)
D2: JP3.5, U1.19 (PB10)
D3~: JP3.6, U1.20 (PB11)
D4: JP3.7, U1.12 (PA07)
D5~: JP3.8, U1.10 (PA05)
D6~: JP3.9, U1.9 (PA04)
D7: JP3.10, U1.11 (PA06)
D8: JP3.11, U1.27 (PA18)
D9~: JP3.12, U1.29 (PA20)
D10~: JP3.13, U1.30 (PA21)
GND: C1.2, C2.2, C5.2, C7.2, DL1.C, DL2.C, J1.5, J3.GND1 (GND), J3.GND2 (GND), J4.5, JP2.14, JP3.4, PB1.1 (3), PB1.2 (3), PB1.3, PB1.4 (3), PB1.5 (1), R1.1, U3.1 (SDO/SA0), U3.2 (SDX), U3.3 (SCX), U3.6 (GND), U3.7 (GND); also elsewhere on the board
MISO~: JP3.15, U1.28 (PA19)
MOSI: JP3.14, U1.25 (PA16)
unnamed: C1.1, D1.1, J1.6 (SH), J1.7 (SH), J1.8 (SH), J1.9 (SH), J1.10 (SH), J1.11 (SH), R1.2
unnamed: DL2.A, R2.1
unnamed: DL1.A, R3.1
unnamed: J3.SIG, U2.13 (ANT)
unnamed: JP2.12, SJ1.2
PA12_S2_TX/MOSI: U1.21 (PA12), U2.36 (GPIO12)
PA13_S2_RX/MISO: U1.22 (PA13), U2.1 (SPIV_DI/GPIO23)
PA14_S2_RTS/CS: U1.23 (PA14), U2.21 (UART_CTS/RMII_TXD0/SPIV_D0/GPIO19), U2.28 (SPIV_CS/GPIO5)
PA15_S2_CTS/SCK: U1.24 (PA15), U2.20 (UART_RTS/RMII_TXD1/SPIV_WP/GPIO22), U2.29 (SPIV_CLK/GPIO18)
PA27_GPIO0: TP_GPIO0.X, U1.39 (PA27), U2.27 (RMII_CLK/GPIO0)
PA28_ACK: U1.41 (PA28), U2.7 (GPIO33)
PA30_SWCLK: J4.3, R4.1, U1.45 (PA30/SWCLK)
PA31_SWDIO: J4.2, U1.46 (PA31/SWDIO)
RESETN: C2.1, J4.6, JP2.13, JP3.3, PB1.6 (2), R5.1, U1.40 (RESETN)
RSTN_NINA: R7.1, TP_RST.X, U1.13 (PA08), U2.19 (RESET_N)
RX: JP3.2, U1.38 (PB23)
RX_NINA_PROG: TP_RX.X, U1.32 (PA23), U2.22 (UART_TXD/GPIO1)
SCK: JP2.1, R3.2, U1.26 (PA17)
TX: JP3.1, U1.37 (PB22)
TX_NINA_PROG: TP_TX.X, U1.31 (PA22), U2.23 (UART_RXD/GPIO3)
USB_N: D1.3, D-.X, J1.2, U1.33 (PA24/USB_DM)
USB_P: D1.2, D+.X, J1.3, U1.34 (PA25/USB_DP)
VIN: JP2.15; also elsewhere on the board
VUSB: D1.4, J1.1, SJ1.1; also elsewhere on the board

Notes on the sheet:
RESET
Crypto Auth
Arturo Guadalupi

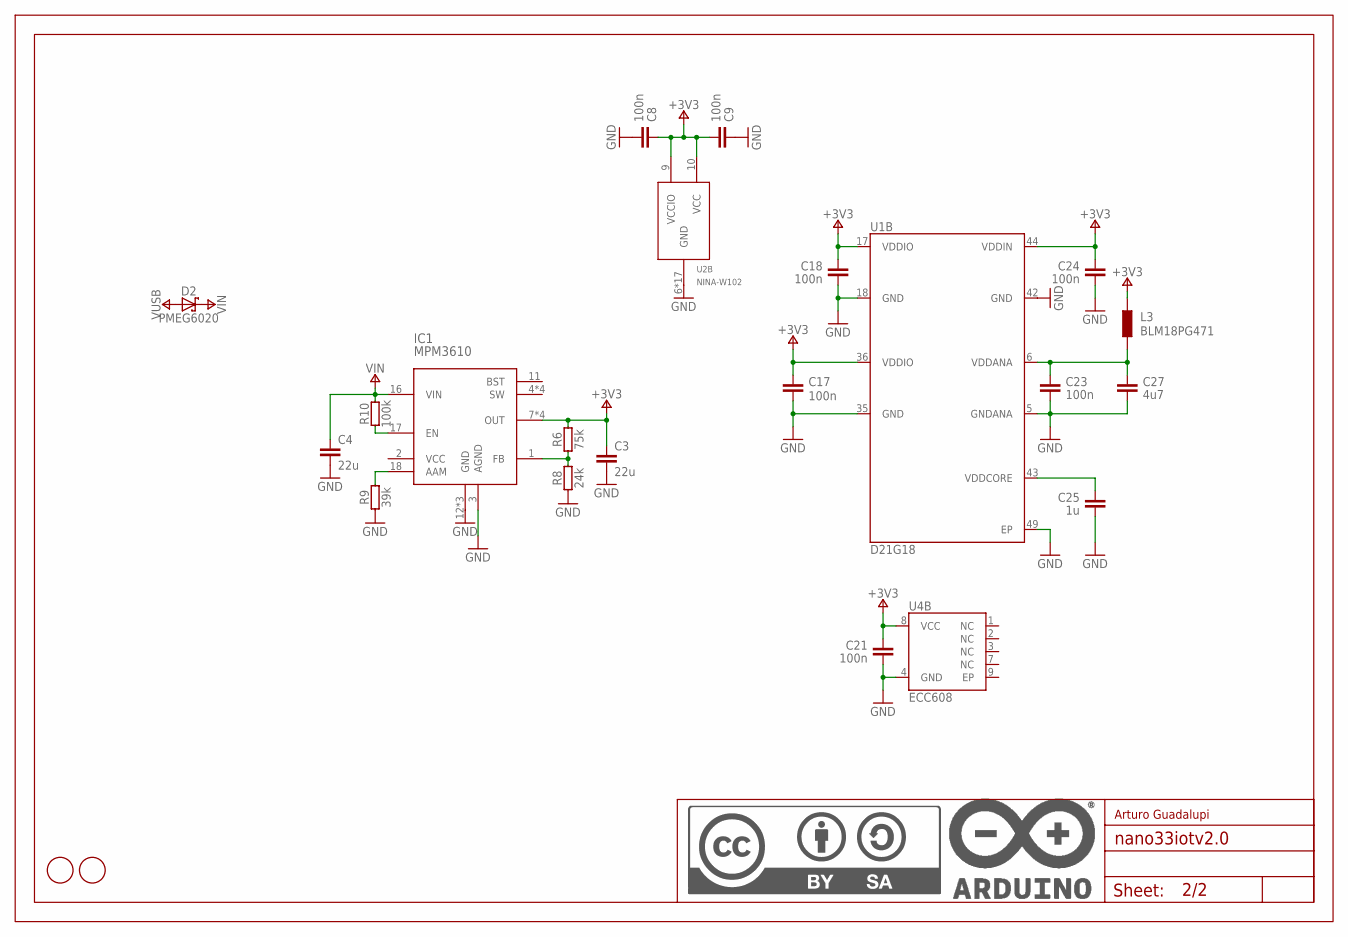
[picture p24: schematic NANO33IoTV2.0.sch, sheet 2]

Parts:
C3, C4: 22u; 0805-R2013X50N
C8, C9, C17, C18, C21, C23, C24: 100n; 0402-1005X55N
C25: 1u; 0402-1005X55N
C27: 4u7; 0603-1608X90N
D2: PMEG6020; SODFL3517X110N
FD1, FD2: DNP; FD-1-1.5
IC1: MPM3610
L3: BLM18PG471; 0603-1608X90N
R6: 75k; 0402-1005X55N
R8: 24k; 0402-1005X55N
R9: 39k; 0402-1005X55N
R10: 100k; 0402-1005X55N
U1: D21G18; QFN50P700X700X90-49XN-EPSQ515
U2: NINA-W102; NINA-W1X
U4: ECC608; SON50P300X200X60-9N-EP160X140
U$1: DNP; FRAME

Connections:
+3V3: C3.1, C8.1, C9.2, C17.1, C18.1, C21.1, C24.1, IC1.7 (OUT), IC1.8 (OUT), IC1.9 (OUT), IC1.20 (OUT), L3.1, R6.2, U1.17 (VDDIO), U1.36 (VDDIO), U1.44 (VDDIN), U2.9 (VCCIO), U2.10 (VCC), U4.8 (VCC); also elsewhere on the board
GND: C3.2, C4.2, C8.2, C9.1, C17.2, C18.2, C21.2, C23.2, C24.2, C25.2, C27.2, IC1.3 (AGND), IC1.12 (GND), IC1.13 (GND), IC1.14 (GND), R8.1, R9.1, U1.5 (GNDANA), U1.18 (GND), U1.35 (GND), U1.42 (GND), U1.49 (EP), U2.6 (GND), U2.12 (GND), U2.14 (GND), U2.26 (GND), U2.30 (GND), U2.GND@1 (GND), U2.GND@2 (GND), U2.GND@3 (GND), U2.GND@4 (GND), U2.GND@5 (GND), U2.GND@6 (GND), U2.GND@7 (GND), U2.GND@8 (GND), U2.GND@9 (GND), U2.GND@10 (GND), U2.GND@11 (GND), U2.GND@12 (GND), U4.4 (GND); also elsewhere on the board
N17852357: C23.1, C27.1, L3.2, U1.6 (VDDANA)
N17852431: C25.1, U1.43 (VDDCORE)
unnamed: IC1.1 (FB), R6.1, R8.2
unnamed: IC1.18 (AAM), R9.2
unnamed: IC1.17 (EN), R10.1
VIN: C4.1, D2.C, IC1.16 (VIN), R10.2; also elsewhere on the board
VUSB: D2.A; also elsewhere on the board

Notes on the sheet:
Arturo Guadalupi

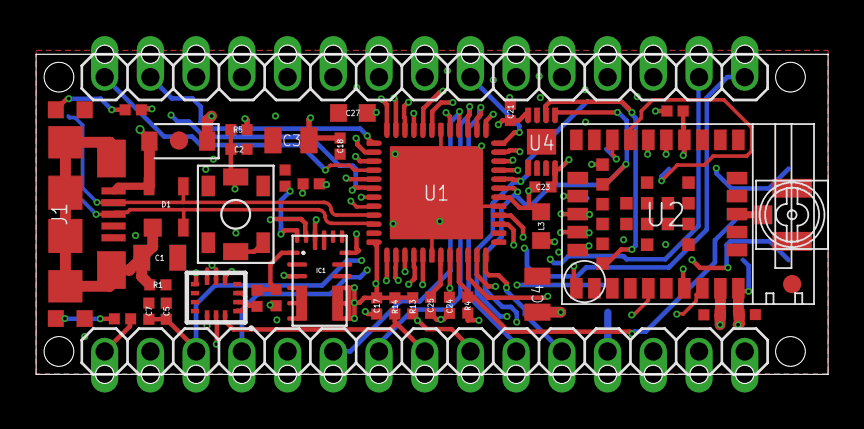
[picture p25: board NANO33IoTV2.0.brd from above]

Board: 4 copper layers, 44.0 x 17.8 mm, 54 parts (1 on the bottom side), 51 nets.

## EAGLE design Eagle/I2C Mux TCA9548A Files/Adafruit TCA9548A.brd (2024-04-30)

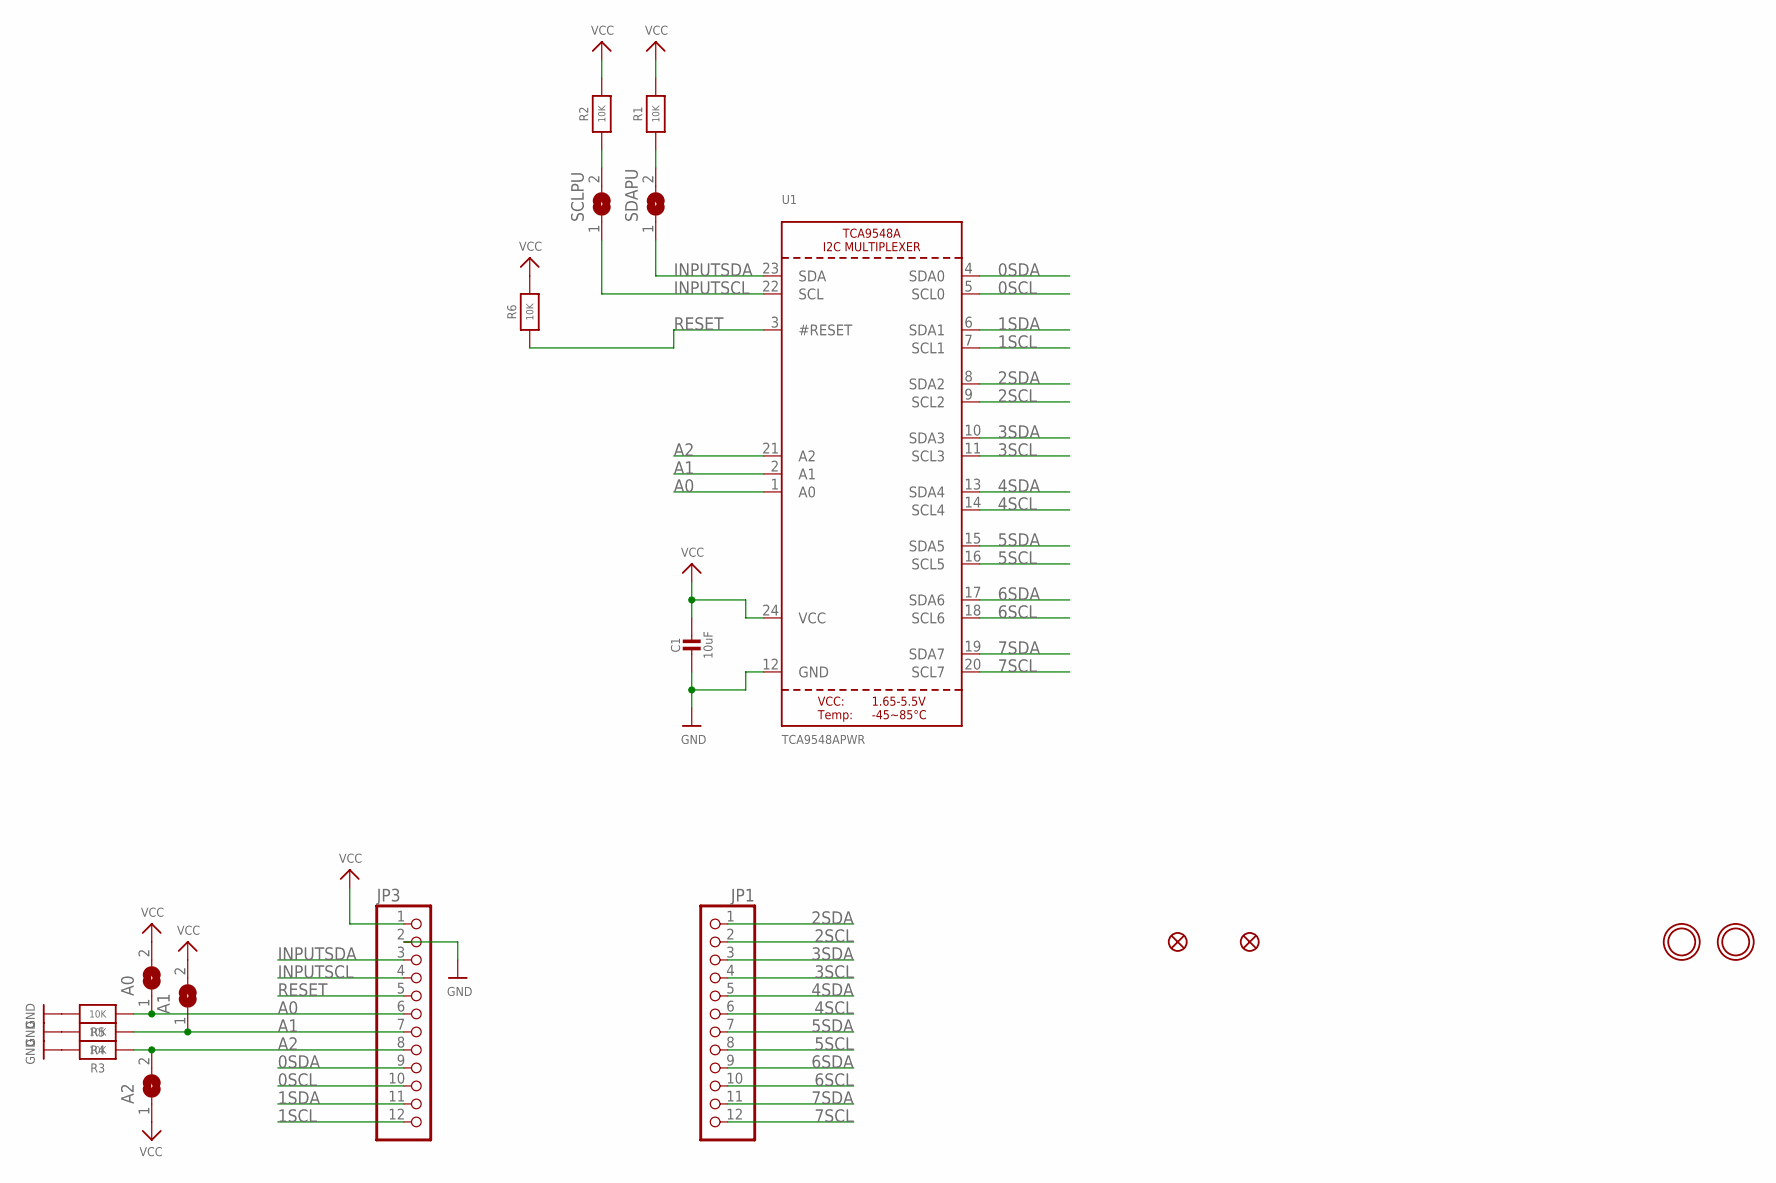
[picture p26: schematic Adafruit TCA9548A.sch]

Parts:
A0, A1, A2: SOLDERJUMPER; SOLDERJUMPER_ARROW_NOPASTE
C1: 10uF; 0805-NO
FID1, FID3: FIDUCIAL""; FIDUCIAL_1MM
JP1, JP3: HEADER-1X12; 1X12_ROUND
R1, R2, R3, R4, R5: 10K; 0805-NO
R6: 10K; _0805MP
SCLPU: SOLDERJUMPERCLOSED; SOLDERJUMPER_CLOSEDWIRE
SDAPU: SOLDERJUMPERCLOSED; SOLDERJUMPER_CLOSEDWIRE
U1: TCA9548APWR; TSSOP24
U$4, U$5: MOUNTINGHOLE2.5; MOUNTINGHOLE_2.5_PLATED

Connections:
0SCL: JP3.10, U1.5 (SCL0)
0SDA: JP3.9, U1.4 (SDA0)
1SCL: JP3.12, U1.7 (SCL1)
1SDA: JP3.11, U1.6 (SDA1)
2SCL: JP1.2, U1.9 (SCL2)
2SDA: JP1.1, U1.8 (SDA2)
3SCL: JP1.4, U1.11 (SCL3)
3SDA: JP1.3, U1.10 (SDA3)
4SCL: JP1.6, U1.14 (SCL4)
4SDA: JP1.5, U1.13 (SDA4)
5SCL: JP1.8, U1.16 (SCL5)
5SDA: JP1.7, U1.15 (SDA5)
6SCL: JP1.10, U1.18 (SCL6)
6SDA: JP1.9, U1.17 (SDA6)
7SCL: JP1.12, U1.20 (SCL7)
7SDA: JP1.11, U1.19 (SDA7)
A0: A0.1, JP3.6, R5.1, U1.1 (A0)
A1: A1.1, JP3.7, R4.1, U1.2 (A1)
A2: A2.2, JP3.8, R3.1, U1.21 (A2)
GND: C1.2, JP3.2, R3.2, R4.2, R5.2, U1.12 (GND)
INPUTSCL: JP3.4, SCLPU.1, U1.22 (SCL)
INPUTSDA: JP3.3, SDAPU.1, U1.23 (SDA)
unnamed: R2.1, SCLPU.2
unnamed: R1.1, SDAPU.2
RESET: JP3.5, R6.1, U1.3 (#RESET)
VCC: A0.2, A1.2, A2.1, C1.1, JP3.1, R1.2, R2.2, R6.2, U1.24 (VCC)

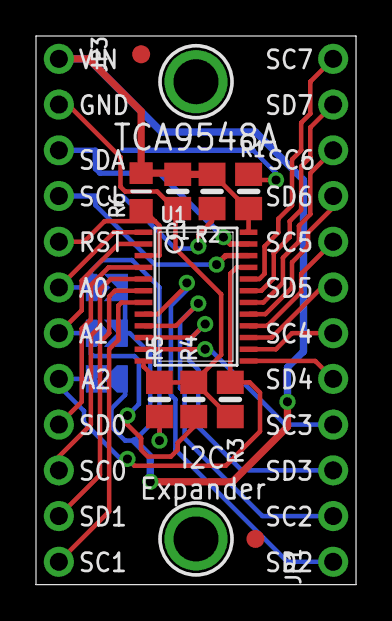
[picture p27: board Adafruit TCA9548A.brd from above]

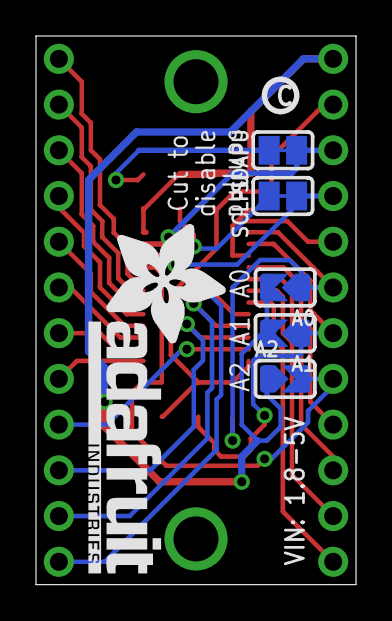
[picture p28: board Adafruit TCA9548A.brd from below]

Board: 2 copper layers, 17.8 x 30.5 mm, 21 parts (7 on the bottom side), 26 nets.

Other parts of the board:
U$6: PCBFEAT-REV-040
U$7: ADAFRUIT_TEXT_20MM

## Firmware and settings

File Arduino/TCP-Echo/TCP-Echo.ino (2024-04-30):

/*
  Will Bradford
  Echo server script

  Inrements received ASCII character by 1 and sends it via TCP socket
 */

#include <SPI.h> 
#include <WiFiNINA.h>
#include "network_cred.h"
#include "Adafruit_DRV2605.h"

// Mux I2C address
#define TCAADDR 0x70
const bool debug = true;   // Toggle debug mode (Toggle program being verbose)

// Set network credentials (from network_cred.h)
#define ssid mySSID_0
#define password myPASSWORD_0

Adafruit_DRV2605 drv1;

int status = WL_IDLE_STATUS;

WiFiServer server(8888);

// Select which driver to talk to
void muxSelect(uint8_t i) {
  if (i > 7) {
    if (debug) { Serial.println("Invalid mux line selected."); }
    return;
  }
  Wire.beginTransmission(TCAADDR);
  Wire.write(1 << i);
  Wire.endTransmission();
}

// Initialize a driver
void drvInit(Adafruit_DRV2605* driver, int drvNum) {
  muxSelect(drvNum);
  if (!driver->begin()) {
    if (debug) {
      Serial.print("Could not find DRV2605 number ");
      Serial.println(drvNum);
    }
    while (1) delay(10);
  }
  driver->selectLibrary(1);  // Libraries 1-5 are for ERM motors, library 6 is for LRA motors
  driver->setMode(DRV2605_MODE_INTTRIG);
}

// Change the playback effect pattern of the DRV2605 drivers
void changeEffect(Adafruit_DRV2605* driver, int effectNum, int drvNum) {
  muxSelect(drvNum);
  if (effectNum > 0) {  // Set new playback effect
    if (debug) {
      Serial.print("Setting the effect ID of driver ");
      Serial.print(drvNum);
      Serial.print(" to ");
      Serial.println(effectNum);
    }

    if (effectNum > 123) {  // Truncate out-of-bounds numbers to the last available effect (ID# 123)
      effectNum = 123;
    }
    driver->setWaveform(0, effectNum);  // Desired effect
    driver->setWaveform(1, 0);          // End waveform

    if (debug) {
      Serial.print("Effect ID of driver ");
      Serial.print(drvNum);
      Serial.print(" set to ");
      Serial.println(effectNum);
    }
  } else if (effectNum == 0) {  // Stop driver
    if (debug) {
      Serial.print("Stopping driver number ");
      Serial.print(drvNum);
      Serial.println(".");
    }

    driver->stop();

    if (debug) {
      Serial.print("Driver number ");
      Serial.print(drvNum);
      Serial.println(" stopped.");
    }
  } else {  // Do nothing if effectNum < 0
    if (debug) {
      Serial.print("The settings of driver number ");
      Serial.print(drvNum);
      Serial.println(" have not been changed.");
    }
  }
  if (debug) { Serial.println(); }  // Print newline for easier reading
}

// Taken from WiFiNINA example script WiFiWebServer
void printWifiStatus() {
  // print the SSID of the network you're attached to:
  Serial.print("SSID: ");
  Serial.println(WiFi.SSID());

  // print your board's IP address:
  IPAddress ip = WiFi.localIP();
  Serial.print("IP Address: ");
  Serial.println(ip);

  // print the received signal strength:
  long rssi = WiFi.RSSI();
  Serial.print("signal strength (RSSI):");
  Serial.print(rssi);
  Serial.println(" dBm");
}

void setup() {
  Serial.begin(9600);
  Wire.begin();
  pinMode(LED_BUILTIN, OUTPUT);

  // Initialize drivers
  drvInit(&drv1, 1);

  // check for the WiFi module:
  if (WiFi.status() == WL_NO_MODULE) {
    Serial.println("Communication with WiFi module failed!");
    // Don't continue
    while (true);
  }

  String fv = WiFi.firmwareVersion();
  if (fv < WIFI_FIRMWARE_LATEST_VERSION) {
    Serial.println("Please upgrade the firmware");
  }

  // Set static local IP (this will vary by network host)
  IPAddress local_IP(172, 16, 1, 4);

  // Set gateway IP address (router's IP)
  IPAddress gateway(172, 16, 1, 1);
  IPAddress dns(172, 16, 1, 1);
  IPAddress subnet(255, 255, 0, 0);

  // Attempt to connect to WiFi network:
  while (status != WL_CONNECTED) {
    Serial.print("Attempting to connect to SSID: ");
    Serial.println(ssid);

    // Configurate network
    WiFi.config(local_IP, dns, gateway, subnet);
    status = WiFi.begin(ssid, password);
    delay(100);

    while (WiFi.status() != WL_CONNECTED) {
      delay(500);
      Serial.print(".");
      delay(500);
    }
  }
  server.begin();
  printWifiStatus();
}


void loop() {
  // Listen for incoming clients
  WiFiClient client = server.available();
  if (client) {
    Serial.println("new client");
    while (client.connected()) {
      if (client.available() > 0) {
        
        String oldPacket = String(client.readStringUntil('\n'));
        int msgLength = oldPacket.length() + 1; // + 1 for null terminator
        char msgArray[msgLength];
        oldPacket.toCharArray(msgArray, msgLength);

        Serial.println(msgArray);
        Serial.println();

        //digitalWrite(LED_BUILTIN, HIGH);
        //changeEffect(&drv1, 64, 1);
        //drv1.go();
        //delay(2000);
        //digitalWrite(LED_BUILTIN, LOW);
        //changeEffect(&drv1, 0, 1);
        //drv1.go();

        // Increment received message
        int newASCIIPacket = int(msgArray[0]);
        char newPacket = newASCIIPacket + 1;
        //char newPacket = 'B';
        
        // Send new message
        client.println(newPacket);
      }
    }
    // Close connection
    client.stop();
    Serial.println("client disconnected");
  }
}

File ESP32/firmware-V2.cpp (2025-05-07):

/*
  Will Bradford and Ryan Frost
  Haptic Glove V2 Firmware

  Due to C++ magic, message parser behavior is weird when passing values for less than 8 motors. Pass values for
    all 8 to be safe

  test messege: E,100,43,55,1,123,34,99,2
*/

#include "utils.h"

MotorDriverSet* drvs;
CommandMessage* command;
WiFiObj* wifiObj;
IMUObj* imuObj;
WiFiServer* server = new WiFiServer(WIFI_PORT);

void setup()
{
  Serial.begin(9600);
  Wire.begin(SDA_PIN, SCL_PIN);
  pinMode(LED_BUILTIN, OUTPUT);
  pinMode(CLIENT_CONNECTED_PIN, OUTPUT);
  pinMode(MESSAGE_RECEIVED_PIN, OUTPUT);
  delay(2000);

  // Start serial connection
  if (DEBUG) {
    while (!Serial) // This will cause an issue if you don't open the serial port on computer
    {
      delay(1);
    }
    Serial.println("Booting Up");
  }

  Wire.beginTransmission(MUXADDR);
  byte error = Wire.endTransmission();

  if (error != 0) {
    while (true) {
      // Flash LED
      Serial.println("Multiplexer not found");
      delay(500);
    }
  }

  // Tie mux RST high
  pinMode(MUXRST, OUTPUT);
  digitalWrite(MUXRST, HIGH);

  // Initialize global variables
  drvs = new MotorDriverSet(MAX_MOTORS);
  command = new CommandMessage(MAX_MOTORS, drvs);

  wifiObj = new WiFiObj(
    *server,                             // server
    IPAddress(172, 16, 1, DEVICE_ID),   // local_IP
    IPAddress(172, 16, 1, 1),           // gateway
    IPAddress(172, 16, 1, 1),           // dns
    IPAddress(255, 255, 0, 0)           // subnet
  );
  imuObj = new IMUObj();

  Serial.print("Num drivers: ");
  Serial.println(drvs->numDrvs);

  // Sequentially activate/deactivate drivers
  if (DEBUG)
  {
    Serial.println("Cycling drivers\n");
  }

  drvs->cycle();

  if (DEBUG)
  {
    Serial.println("Drivers cycled\n");
  }

  // Connect to WiFi
  wifiObj->connect();

  // Initialize accelerometer
  imuObj->initialize();

  if (DEBUG)
  {
    Serial.println("System ready for use!");
  }
}

void loop()
{

  //********************************************** Control Via WiFi **********************************************

  // Execute if WiFi connected
  if (WiFi.status() == WL_CONNECTED)
  {
    // Check if a client has connected
    WiFiClient client = wifiObj->server->available();

    // TODO: LED blinking if connected to WiFi but not client. Currently is just on
    if (client)
    { // This evaluates as 0 unless a message has appeared over the TCP socket
      if (client.connected())
      {
        // TODO: LED on if client connected. Currently is on if connected to WiFi
        if (DEBUG)
        {
          Serial.println("Client connected");
        }
      }
      // While client is connected, keep reading messages from client
      while (client.connected())
      {
        digitalWrite(CLIENT_CONNECTED_PIN, HIGH);
        // If a message exists, read it
        if (client.available() > 0)
        {
          // TODO: turn packet into a char array from inception to simplify later code in both the checksum as well as createCmdMsg()

          /*                         Rudimentary draft of checksum implementation

          char packetArray[packet.length() + 1]; // + 1 for null terminator
          packet.toCharArray(packetArray, packet.length() + 1);

          // Check to detect data corruption
          uint8_t check = 0x0;

          if (debug) { Serial.println("\nChecking for data corruption..."); Serial.print("Check is "); Serial.println(check);}
          // XOR all bytes in the recieved message (including the checksum)
          for (uint8_t data : packetArray) {
            if (debug) {Serial.print("data is "); Serial.println(data);}
            check^=data;
            if (debug) {Serial.print("Check is now "); Serial.print(check);Serial.println("\n");}
          }
          if (debug) {
            Serial.print("Final value of check is "); Serial.println(check);
            Serial.print("Check should now equal "); Serial.println(MAGIC_BYTE);
          }

          // Check for corruption
          if (check == MAGIC_BYTE) {
            if (debug) {Serial.println("No data corruption detected");}


          }
          else {
            if (debug) {Serial.println("Data corruption detected");}
          }
                                End of rudimentary draft of checksum implementation
          */
          digitalWrite(MESSAGE_RECEIVED_PIN, HIGH);
          command->recievePacket(client);
          digitalWrite(MESSAGE_RECEIVED_PIN, LOW);
        }
        // if (imuObj->accelToggle)
        // {
        //   imuObj->getAcceleration();

        //   // Send acceleration data to client
        //   client.println(imuObj->outMsg); // Does this placement give the computer on the other end enough time to read the accel data before client.flush() is called below?
        // }
        drvs->go(); // Continuously play effects while client connected
      }
      // Replace 5 with your pin number
      digitalWrite(CLIENT_CONNECTED_PIN, LOW);
      if (DEBUG)
      {
        Serial.println("Client disconnected\n");
      }

      // Stop client, accelerometer, and drivers on client disconnect
      client.stop();
      imuObj->accelToggle = false;
      if (DEBUG)
      {
        Serial.println("Accelerometer stopped\n");
      }
      drvs->stop();

      // TODO: Make LED blink when connected to WiFi but not client. Currently is just on for both cases
    }
  }
  else
  {
    // LED off if connection lost
    if (DEBUG)
    {
      Serial.println("Network connection lost");
    }
    digitalWrite(LED_BUILTIN, LOW);

    // Restart WiFi connection
    WiFi.disconnect();
    WiFi.mode(WIFI_OFF);
    wifiObj->connect();
  }

  //********************************************* Control Via Serial *********************************************
  if (Serial.available() > 0)
  {
    command->recievePacket();
  }
  // while (imuObj->accelToggle)
  // { // Continuously spit out accel data until another message is read over Serial
  //   imuObj->getAcceleration();

  //   // TODO: Save accel data or maybe write it to a file to connected computer via Serial?
  //   if (Serial.available() > 0)
  //   {
  //     command->recievePacket();
  //   }
  //   drvs->go();
  // }
  // Serial.flush(); // Is this needed? "Waits for the transmission of outgoing serial data to complete"

  // Continuously play effects after message receival 
  // E,47,47,47,47,47,47,47,47
  // E,100,43,55,1,123,34,99,2
  // E,0,0,0,0,0,0,0,0 
  // E,0,0,0,0,0,0,0,0
  drvs->go();
}

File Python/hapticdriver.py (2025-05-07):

"""Module to define a haptic glove class.

Version: 4/25/24
"""
import math
import numpy as np
import socket
from threading import Thread
import time


def find_distance(vector1, vector2, normalized=False):
    """Find the normalized distance between two vectors

    :param vector1: First vector
    :param vector2: Second vector
    :param normalized: Whether to normalize vectors first
    """
    if normalized:
        vector1 = vector1 / np.linalg.norm(vector1)
        vector2 = vector2 / np.linalg.norm(vector2)
    diff = vector1 - vector2
    distance = np.linalg.norm(diff)
    return distance

def map_to_range(x, in_min, in_max, out_min, out_max, bounded=False): # TODO: Can this be removed for glove 2.0?
    """Map a variable with expected range in_min-in_max to range out_min-out_max. Works like the map function in C++

    :param x: Number to map
    :param in_min: Minimum of input range
    :param in_max: Maximum of input range
    :param out_min: Minimum of output range
    :param out_max: Maximum of output range
    :param bounded: Whether to strictly bound input value to output range
    """
    output = (x - in_min) * (out_max - out_min) / (in_max - in_min) + out_min
    if bounded:
        if output < out_min:
            output = out_min
        if output > out_max:
            output = out_max
    return output

def reverse_map_to_range(x, in_min, in_max, out_min, out_max, bounded=False): #TODO: Can this be removed for glove 2.0?
    """Inversely map a variable with expected range in_min-in_max to range out_min-out_max.

    :param x: Number to map
    :param in_min: Minimum of input range
    :param in_max: Maximum of input range
    :param out_min: Minimum of output range
    :param out_max: Maximum of output range
    :param bounded: Whether to strictly bound input value to output range
    """
    output = (x - in_min) * (out_max - out_min) / (in_max - in_min) + out_min
    if bounded:
        if output > out_min:
            output = out_min
        if output < out_max:
            output = out_max
    return output

def find_intensity_array(current_pos, goal_pos, motor_positions, accel = np.array([0.0,0.0,0.0]), norm = True):
    """Generate array of vibration intensity for motors. (acceleration not implemented yet)

    :param current_pos: Current position of glove
    :param goal_pos: Goal position of glove
    :param motor_positions: Position of motors on the hand
    :param accel: acceleration
    :param norm: Whether to normalize vectors first
    """
    # Normalize all vectors
    if norm:
        if np.linalg.norm(current_pos) != 0:
            current_pos = current_pos / np.linalg.norm(current_pos)
        if np.linalg.norm(goal_pos) != 0:
            goal_pos = goal_pos / np.linalg.norm(goal_pos)
        if np.linalg.norm(accel) != 0:
            accel = accel / np.linalg.norm(accel)

    # Calculate displacement to goal and find distance
    U = goal_pos - current_pos - accel
    D = np.linalg.norm(U)

    # Map the distance value to motor command values
    # I is the maximum that a single motor can be driven
    # I will be proportionally distributed across motors that are closest to the displacement vector
    I = map_to_range(D, 0, 1, 150, 255,  bounded=True) # TODO: See comments at function creation

    motor_distance = [0.0,0.0,0.0,0.0]
    mapped = [0.0,0.0,0.0,0.0]

    # Find the distance between the displacement vector and motors
    # Calculate distributions of vibration to each motor
    for i in range(0, len(motor_positions)):
        motor_distance[i] = find_distance(U, motor_positions[i], normalized=norm)
        # Bound the proportion of vibration sent to a single motor
        mapped[i] = reverse_map_to_range(motor_distance[i], 0.0, math.sqrt(2), 1, .59, bounded=True) # TODO: See comments at function creation

    # Cast distributions of vibration to motors to a numpy array
    mapped = np.array(mapped)
    # Scale distribution by the global maximum vibration
    intensity = np.array(I * mapped).astype(int)
    return intensity

class HapticDriver:
    """
    Glove object
    Supports versions with and without accelerometer
    Used for manual operation and testing
    """

    pFactor = 1.0  # Power factor scales maximum intensity of motor vibrations

    # Motor coordinate arrays that will be switched between based on acceleration data
    motors = np.array([np.array([0.0, pFactor, 0.0]), np.array([0.0, -pFactor, 0.0]), np.array([-pFactor, 0.0, 0.0]),
                       np.array([pFactor, 0.0, 0.0])])  # standard position
    motors_UD = np.array([np.array([0.0, -pFactor, 0.0]), np.array([0.0, pFactor, 0.0]), np.array([pFactor, 0.0, 0.0]),
                          np.array([-pFactor, 0.0, 0.0])])  # upside down
    motors_R = np.array([np.array([pFactor, 0.0, 0.0]), np.array([-pFactor, 0.0, 0.0]), np.array([0.0, pFactor, 0.0]),
                         np.array([0.0, -pFactor, 0.0])])  # rolled right
    motors_L = np.array([np.array([-pFactor, 0.0, 0.0]), np.array([pFactor, 0.0, 0.0]), np.array([0.0, -pFactor, 0.0]),
                         np.array([0.0, pFactor, 0.0])])  # rolled left

    def __init__(self, device_id, port, acceleration=False, verbose=True) -> None:
        # Initialize object variables
        self.connected = False
        self.device_id = device_id
        self.verbose = verbose
        # Automatically find glove IP with device_id
        # self.TCP_IP = find_device_ip(self.device_id)

        # TODO: remove automatic lookup to avoid error when multiple NICs are present
        # IP is hard coded to 172.16.1.X based upon Apple AirPort router
        self.TCP_IP = "172.16.1." + str(device_id)
        self.TCP_PORT = port
        self.acceleration = acceleration
        # If using accelerometer, initialize acceleration vectors
        if acceleration:
            self.accel_data = np.array([0.0, 0.0, 0.0, 0.0])
            #self.accel_norm = np.array([0.0, 1.0, 0.0])
        # Set initial conditions
        self.current_vector = np.array([0.0, 1.0, 0.0])
        self.glove_position = np.array([0.0, 0.0, 0.0])
        # Set default motors
        self.current_motors = self.motors

        # create global flag to indicate glove shutdown
        self.shutdown = False

    def connect(self):
        """Connect to the glove via TCP socket"""
        try:
            self.s = socket.socket(socket.AF_INET, socket.SOCK_STREAM)
            self.s.settimeout(10)
            self.s.connect((self.TCP_IP, self.TCP_PORT))
            self.connected = True
            # If using accelerometer, spawn thread and tell it to read constantly
            if self.acceleration:
              self.accel_loop = True
              self.acceleration_thread = Thread(target=self.__get_acceleration).start()
        except:
            if self.verbose:
                print(f'Failed to connect to ip {self.TCP_IP}')
            return False

        return True

    def disconnect(self):
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

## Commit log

2022-02-03 Added push/pull mode switch
2022-02-11 Update motor control protocol
2022-02-15 Add Eagle files
    [Haptic_Motor_Driver_DRV2605L_v20.brd, Haptic_Motor_Driver_DRV2605L_v20.sch, Triple_Axis_Accelerometer-Gyro_Breakout_-_MPU-6050_v12.sch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]
2022-02-18 Board schematic
    [SparkFun_LiPo_Charger_Plus.brd, SparkFun_LiPo_Charger_Plus.sch, haptic_glove.sch]
2022-02-18 board schematic update
    [haptic_glove.brd]
2022-02-22 Updated schematic and board design
    [haptic_glove.brd, haptic_glove_0_1.brd, haptic_glove_0_1.sch]
2022-02-22 Updated board design
    [haptic_glove_0_1.brd]
2022-02-23 Modified board design
    [haptic_glove_0_1.brd, haptic_glove_0_1.sch]
2022-02-23 Added board images
2022-02-28 Added BOM
    [Haptic_Glove_Clean_BOM.xlsx, haptic_glove_0_1.brd, haptic_glove_0_1_BOM.csv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]
2022-03-01 Added supplier BOM's
    [Digikey_Cart.xlsx, Digikey_Cart_2.xlsx, Haptic_Glove_Clean_BOM.xlsx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]
2022-03-07 Added board V1.1
2022-03-07 Deleted cache files
    [haptic_glove_0_1.brd]
2022-04-13 Refactor, added motor test sequence
2022-04-27 Accelerometer compensation quantized
2022-05-09 Added accelerometer thread
2022-05-12 Add BoMs for different revisions
    [Breadboard Prototype.xlsx, PCB Prototype.xlsx]
2022-10-07 Loop for increasing each motor's intensity
2022-10-13 Re-organize so can be Arduino sketch
2022-11-08 Add image schematic for rev02
2023-09-26 Change IP lookup to resolve multiple NICs issue
    [glove.py]
2023-09-29 Update device IDs and trigger keys to work with two gloves
2023-11-10 Rich feedback pattern demos using 2 drivers
2023-11-10 Revert "Rich feedback pattern demos using 2 drivers"
    This reverts commit 424b502ffc2a4a7bbe3d1f6ce05d2d9a62003c54.
    [DRV-demo-basic.ino, DRV-demo-complex.ino]
2024-01-26 Specify device ID requirements
2024-02-02 Add board files
    [haptic-glove-2.brd, haptic-glove-2.sch]
2024-02-02 Add board files in a folder
    [haptic-glove-2.brd, haptic-glove-2.sch]
2024-02-02 Add haptic driver Eagle files
    [Adafruit DRV2605L.brd, Adafruit DRV2605L.sch]
2024-02-02 Add mux Eagle files
    [Adafruit TCA9548A.brd, Adafruit TCA9548A.sch]
2024-02-02 Add I2C Scanner script for mux
2024-02-02 Add PCB images
2024-02-28 Added board schematic
2024-02-28 Refactor and add new board images
2024-02-28 Refactor board files
    [haptic-glove-2.brd, haptic-glove-2.sch]
2024-02-28 Add work in progress 2.1 files
    [haptic-glove-2.1.brd, haptic-glove-2.1.sch]
2024-03-05 Add motor housing SolidWorks and .STL files
    [Haptic motor housing.SLDPRT, Haptic motor housing.STL]
2024-03-07 Add V2.1 board images
2024-03-07 Add fully updated V2.1 board files
    [haptic-glove-2.1.brd, haptic-glove-2.1.sch]
2024-03-09 Add Arduino IDE set up tutorial photos
2024-03-09 Refactor board images
2024-03-09 Refactor Board Images/V2.0/glove-2.0-bottom.png
2024-03-09 Refactor Board Images/V2.0/glove-2.0-top.png
2024-03-09 Refactor Board Images/V2.1/glove-2.1-sch.pdf
2024-03-09 Refactor Board Images/V2.1/glove-2.1-sch.png
2024-03-09 Refactor Board Images/V2.1/glove-V2.1-bottom.png
2024-03-09 Refactor Board Images/V2.1/glove-V2.1-top.png
2024-03-25 Add Arduino Eagle files for reference
    [NANO33IoTV2.0.brd, NANO33IoTV2.0.sch]
2024-03-28 Add updated V2.1 .brd file
    [haptic-glove-2.1.brd]
2024-03-28 Revert to old JST-PH connector
    [haptic-glove-2.1.sch]
2024-03-28 Add Board images
2024-04-02 Add text for correct Arduino orientation
    [haptic-glove-2.1.brd]
2024-04-02 Add text to denote correct Arduino orientation
2024-04-12 Implemented software bandage for WiFi disconnect (only using first 7 drivers)
2024-04-23 WiFi code, accel implementation, 8th driver toggle
    Consolidated WiFi connection code,
    made it to where the accelerometer collects data continuously once an accel message is received until a new message is received,
    added a toggle to activate/deactivate use of the 8th motor driver
2024-04-25 Removed the ability to edit the number of motors used
2024-04-25 Fix accel thread to work with new message structure
    [glove.py]
2024-04-25 Update demo to work with new accel thread
2024-04-25 Update multi glove demo to work with new accel thread
2024-07-11 Rename object to haptic driver
2024-07-19 Set 10s socket timeout
2024-07-19 Arm movement patterns
    lateral, rotation, flexion
2024-07-19 Haptic Arm Demo w/ 7 motors
2024-07-19 Enable 8th driver and disable 4th
2024-09-19 Calculating Joints Work
    [joint_angle_test_data.csv, joint_angle_test_data_1_001.csv, julia-skeleton-walking.csv]
2024-09-23 Joint Angle Update
    [joint_angle_test_data_001.csv, joint_angle_test_data_002.csv]
2024-10-01 Joint Angle with Abby and Sammy Data
    [Abby_Bicep_Curls.csv, Sammy_Bicep_Curls.csv]
2024-10-04 Created new struct and added dynamic number of motors
2026-09-11 Pull glove-control code out of summer2024-rev
    Brings over the reusable Python glove-control scripts written during
    Julia's honors thesis work, separate from her MOCAP analysis/data
    (which stays only on summer2024-rev):
    - glove_quandrant.py / haptic_arm_demo.py: bug fixes (disconnect()
    call, loop-variable shadowing of `time`, updated device_id)
    - feedback_method_test.py, tapping_method_driver.py: motor-placement
    tapping/feedback driver scripts
    - Haptic Controller (Julia Thesis)/{motor_test,muscle_feedback,
    end_effector_feedback}.py: HapticDriver-based motor control scripts
    Not included (left as config/analysis calls for a human):
    - Arduino/firmware-V2 tweaks (DEVICE_ID, eighth-driver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
    [feedback_method_test.py, haptic_arm_demo.py, motor_test.py]
2026-10-18 Added mutliboard firmware for ESP32 and Nano33

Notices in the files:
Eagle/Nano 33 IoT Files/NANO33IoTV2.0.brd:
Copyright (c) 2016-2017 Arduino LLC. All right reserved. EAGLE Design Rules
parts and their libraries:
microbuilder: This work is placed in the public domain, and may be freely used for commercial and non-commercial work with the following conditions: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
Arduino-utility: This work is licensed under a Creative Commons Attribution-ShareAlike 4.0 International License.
